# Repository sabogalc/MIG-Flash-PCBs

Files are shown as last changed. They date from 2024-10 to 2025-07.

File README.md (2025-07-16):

# MIG Flash PCBs
This repository hosts KiCad projects of the MIG Dumper and Flashcart PCBs. These files should prove very useful towards understanding the inner workings of the devices, especially with the schematics and boardview files. As-is, not much can be done with the board files since the original boards are programmed at the factory. The only way to currently get a working board from these files is by transplanting at minimum the FPGA and the microcontroller from an OEM MIG device to the new board.

> 
> The 8 pins seen above the USB-C port and to the right of the microcontroller in this photo are the ones used to program the board at the factory (see https://docs.espressif.com/projects/esp-idf/en/v5.2/esp32s2/api-guides/dfu.html for more information)

> 
> The flashcart PCB inside of the game enclosure.

Another useful resource found in this repo is the bill of materials for both devices. If you have a MIG device but a part on it has gone bad or is missing, this repository should assist with finding replacement resistors or capacitors of the correct value, or finding part numbers for components such as the toggle button on the Flashcart. For more information on either board, see their folders in the `KiCad Projects` directory.

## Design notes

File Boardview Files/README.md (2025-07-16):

# Boardview Files

## What is a Boardview File?

A boardview file is a netlist of all the connections on a PCB with every component laid out exactly as it is in real life. This modern approach provides a more intuitive way to inspect connections and troubleshoot PCBs compared to traditional schematic diagrams.

## How Can I View These Files?

Much like how there are many PCB EDA software programs out there, there are also many board viewing programs. The two that I have used and recommend are listed below:

1. **[OpenBoardView](https://github.com/OpenBoardView/OpenBoardView)**  
   - **License:** MIT  
   - **Description:** An open-source tool for viewing boardview files. It provides essential features for inspecting PCB layouts.

2. **[FlexBV](https://pldaniels.com/flexbv/)**  
   - **License:** Commercial (free version available)  
   - **Description:** A commercial tool with advanced features for viewing and analyzing boardview files. The free version offers most of the basic functionalities.

### Example View

Below is a screenshot of the MIG Dumper boardview as viewed in FlexBV:

MIG Dumper Boardview

In this view, you can observe the following:
- **Net Highlighting:** The +3V3 net is highlighted in green across the board.
- **Component Table:** A table on the right lists components and their pin numbers associated with +3V3.
- **Designator Information:** The designators, values of resistors and capacitors, and component footprints are all displayed.

### Note on Metadata

The metadata you see (e.g., component values, designators) is stored in the `.obdata` file. As of July 2025, this metadata is viewable only in FlexBV. The `.obdata` format is [open and documented](https://openboarddata.org/), and I would very much like to see the feature added to OpenBoardView.

### How Can I Create Boardview Files for My Own Designs?

All of the boardview files I make for my projects are using [an open-source KiCad plugin](https://github.com/whitequark/kicad-boardview). When I first came across this plugin, it had a few bugs with current versions of KiCad, so I submitted some pull requests and the plugin is back into perfect operating condition.

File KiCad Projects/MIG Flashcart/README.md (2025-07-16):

# MIG Flashcart

### Overview
The Flashcart board is very compact, and it is a bit challenging to solder it by hand. Most of the passive components are the 0201 size, and the 0404 RGB LED in the top right is also extremely small. Additionally, the vias have been trimmed down to a 0.2mm size to accommodate the board's routing.

A series of leaks in July 2021 made the low-level hardware of the Switch game cartridge reader public, and it is powered by an ASIC called [Lotus3](https://switchbrew.org/wiki/Lotus3). I don't know much about how this chip/protocol works, but the FPGA and microcontroller in this flashcart are programmed to communicate on this custom interface. 

### Ordering Specifications
To ensure this board fits in the game enclosure and that it can be read, it should be ordered as a 0.8mm thick board with an ENIG finish. All other options can be left as their default.

### Component Measurements and BOM Discrepancies
I measured the components to the best of my ability, but there may be slight discrepancies. For example, I found it odd that 12 of the capacitors measured as 0.82uF and 4 of them measured as 0.88uF. I suspect that all of them are 0.82uF, and imperfections in the measurements caused the 4 outliers to read higher values. Even so, they were consistently measuring high enough that I felt it best to mark them as 0.88uF in the schematic. This point is a bit moot, however, because I could not find any 0201 capacitors on either Digikey or Mouser for 0.82uF or 0.88uF. As such, the BOMs have some substitutions, such as 1uF capacitors in place of the 0.82uF and 0.88uF ones, but the measurements in the schematic and PCB are what most align with what I measured in real life.

### Can I use these designs to manufacture my own MIG Flashcart?
The answer is the same as in [the corresponding section of the Dumper's README](https://github.com/sabogalc/MIG-Flash-PCBs/tree/main/KiCad%20Projects/MIG%20Dumper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). Due to the firmware encryption on the original boards, making this board from scratch (e.g. without transplanting the original μC and FPGA) proves to be a bit of a challenge.

Importantly though, the programmer board schematic I made for the Dumper will not work for the Flashcart as-is since the Flashcart has no 5V/VBUS signal. The programmer board would need to be modified to have an onboard 3.3V regulator, and then with this signal on the Flashcart's VCC breakout signal, it should work. Should anyone make that programmer board and want to write their own firmware, the instructions for accomplishing this can be found on [Espressif's website in the bootloader mode note](https://docs.espressif.com/projects/esp-idf/en/v5.2/esp32s2/api-guides/dfu.html).

I have assembled this board with parts from the included BOM and confirmed that it works when using the chips from an OEM MIG Flashcart. If you are using the parts from the BOM, the LED has a pin 1 indicator which I will show in a photo below. Make sure that the white squre between the two gold pins is facing into the board towards the crystal oscillator.

WIN_20250714_21_31_24_Pro

Below are some photos of the board from this repository in the flashcart enclosure.


> 
> The cartridge reading a game in the Switch and showing a green status LED.

### KiCad 3D View
Below are screenshots of the board from KiCad's 3D board viewer.
MIG Flashcart Front
MIG Flashcart Back

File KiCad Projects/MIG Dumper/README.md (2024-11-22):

# MIG Dumper

### Overview
This is a very straightforward board design. The FPGA is is the first point of contact with the cartridge, and it takes care of direct communication with the data and clock lines in order to be able to read the onboard cartridge data. The microcontroller then takes this data from the FPGA, and it relays it to the SD card to USB adapter, presumably through SPI (reference [here](https://switchbrew.org/wiki/Gamecard#Protocol)). With data moving to and from the FPGA/microcontroller in SPI, it is very simple to configure the board as if it were reading an SD card, after which the dumper allows the files to be read by any USB-enabled device.

### Ordering Specifications
The original board is a standard 1.6mm thick board, and all other options (soldermask, surface finish, etc.) can be customized to your liking. Please note that if you are using the OEM enclosure, the 4.7uF capacitor for C29 in the included Digikey/Mouser BOMs is too tall to allow for it to fully close. The capacitor on the original board is 0.85mm tall, but the one I included is 1.6mm tall.

### Component Measurements and BOM Discrepancies
I measured the components to the best of my ability, but there may be slight discrepancies. For example, the aforementioned 4.7uF capacitor was read in real life to be 4.5uF, but I could not find a 1206 4.5uF capacitor on either Digikey or Mouser. As such, the BOMs have some substitutions, such as 100nF capacitors instead of 110nF capacitors, but the measurements in the schematic and PCB are what most align with what I measured in real life. For capacitors in the pF range that I could not measure, I referenced the datasheets for the [ECS-400-10-37B2-CKY-TR](https://ecsxtal.com/store/pdf/ECX-1637B2.pdf) and [MAX20022ATIA+](https://www.analog.com/media/en/technical-documentation/data-sheets/max20021-max20022.pdf) to obtain these values.

Additionally, the SD card to USB adapter chip and the cartridge reader are not present in the BOMs because neither part is available on Digikey or Mouser, but you can purchase both of them from AliExpress.

[GL823K-HCY04 chip](https://www.aliexpress.com/item/3256805047594623.html)

[Cartridge reader](https://www.aliexpress.com/item/3256804487003304.html)

### Can I use these designs to manufacture my own MIG Dumper?
Yes and no. I have succesfully transplanted all the parts of an original Dumper to this PCB, and it works perfectly. Building it from scratch with the parts from the included `.csv` and `.xlsx` BOMs does not work, but if you substitute in an OEM FPGA and ESP32, then it works. This is because the firmware for these chips is programmed and encrypted at the factory, as specified in the main landing page's `README`.

While it may be possible to break this encryption (see [here](https://hackaday.com/2024/01/15/breaking-the-flash-encryption-feature-of-espressifs-microcontrollers/)), I am a hardware engineer and not very interested in delving into the firmware side of things. However, I will include a schematic for a programmer board below should anyone want to embark on that journey. The instructions for the boot sequence needed are found at https://docs.espressif.com/projects/esp-idf/en/v5.2/esp32s2/api-guides/dfu.html in the bootloader mode note.

Programmer Schematic

Below is a photo of the board from this repository screwed into the enclosure and reading a gamecard.
MIG Dumper in enclosure

### KiCad 3D View
Below are screenshots of the board from KiCad's 3D board viewer.
MIG Dumper Front
MIG Dumper Back

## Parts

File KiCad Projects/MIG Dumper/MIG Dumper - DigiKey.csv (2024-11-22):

Index | Quantity | Part Number | Manufacturer Part Number | Description | Customer Reference | Available | Backorder | Unit Price | Extended Price USD
1 | 10 | 1276-1946-1-ND | CL10B105KP8NNNC | CAP CER 1UF 10V X7R 0603 |  | 10 | 0 | 0.01200 | 0.12
2 | 7 | 1276-1000-1-ND | CL10B104KB8NNNC | CAP CER 0.1UF 50V X7R 0603 |  | 7 | 0 | 0.08000 | 0.56
3 | 6 | 1276-1040-1-ND | CL10A225KO8NNNC | CAP CER 2.2UF 16V X5R 0603 |  | 6 | 0 | 0.08000 | 0.48
4 | 4 | 1276-3104-1-ND | CL31B106KOHNFNE | CAP CER 10UF 16V X7R 1206 |  | 4 | 0 | 0.21000 | 0.84
5 | 2 | 399-C0603C100J5GACTUCT-ND | C0603C100J5GACTU | CAP CER 10PF 50V C0G/NP0 0603 |  | 2 | 0 | 0.11000 | 0.22
6 | 2 | 399-17488-1-ND | C1206C825K4PACTU | CAP CER 8.2UF 16V X5R 1206 |  | 2 | 0 | 0.90000 | 1.80
7 | 2 | 1276-2189-1-ND | CL10C150JB81PNC | CAP CER 15PF 50V C0G/NP0 0603 |  | 2 | 0 | 0.10000 | 0.20
8 | 1 | 1276-2208-1-ND | CL10C180JB81PNC | CAP CER 18PF 50V C0G/NP0 0603 |  | 1 | 0 | 0.10000 | 0.10
9 | 1 | 1276-1055-1-ND | CL31B475KAHNNNE | CAP CER 4.7UF 25V X7R 1206 |  | 1 | 0 | 0.17000 | 0.17
10 | 1 | 399-C0603C750K5HACTUCT-ND | C0603C750K5HACTU | CAP CER 75PF 50V X8R 0603 |  | 1 | 0 | 0.10000 | 0.10
11 | 3 | P24.3KHCT-ND | ERJ-3EKF2432V | RES SMD 24.3K OHM 1% 1/10W 0603 |  | 3 | 0 | 0.10000 | 0.30
12 | 2 | P10.0KHCT-ND | ERJ-3EKF1002V | RES SMD 10K OHM 1% 1/10W 0603 |  | 2 | 0 | 0.10000 | 0.20
13 | 2 | P5.10KHCT-ND | ERJ-3EKF5101V | RES SMD 5.1K OHM 1% 1/10W 0603 |  | 2 | 0 | 0.10000 | 0.20
14 | 1 | P56.0KHCT-ND | ERJ-3EKF5602V | RES SMD 56K OHM 1% 1/10W 0603 |  | 1 | 0 | 0.10000 | 0.10
15 | 1 | P19.6KHCT-ND | ERJ-3EKF1962V | RES SMD 19.6K OHM 1% 1/10W 0603 |  | 1 | 0 | 0.10000 | 0.10
16 | 1 | P20.0KHCT-ND | ERJ-3EKF2002V | RES SMD 20K OHM 1% 1/10W 0603 |  | 1 | 0 | 0.10000 | 0.10
17 | 1 | P36.5KHCT-ND | ERJ-3EKF3652V | RES SMD 36.5K OHM 1% 1/10W 0603 |  | 1 | 0 | 0.10000 | 0.10
18 | 1 | P330GCT-ND | ERJ-3GEYJ331V | RES SMD 330 OHM 5% 1/10W 0603 |  | 1 | 0 | 0.10000 | 0.10
19 | 1 | P100KHCT-ND | ERJ-3EKF1003V | RES SMD 100K OHM 1% 1/10W 0603 |  | 1 | 0 | 0.10000 | 0.10
20 | 4 | 490-15985-1-ND | LQM21PN1R5MEHD | FIXED IND 1.5UH 1.5A 125MOHM SMD |  | 4 | 0 | 0.33000 | 1.32
21 | 1 | 754-1940-1-ND | APT3216LSECK/J3-PRV | LED RED CLEAR 2SMD |  | 1 | 0 | 0.64000 | 0.64
22 | 1 | 1965-ESP32-S2FH4CT-ND | ESP32-S2FH4 | RF TXRX MODULE WIFI SMD |  | 1 | 0 | 1.48000 | 1.48
23 | 1 | 220-2212-1-ND | ICE40UP5K-SG48I | IC FPGA 39 I/O 48QFN |  | 1 | 0 | 10.10000 | 10.10
24 | 1 | MAX20022ATIA+-ND | MAX20022ATIA+ | IC REG BUCK ADJ 1A QUAD 28TQFN |  | 1 | 0 | 6.59000 | 6.59
25 | 1 | 50-ECS-400-10-37B2-CKY-TRCT-ND | ECS-400-10-37B2-CKY-TR | CRYSTAL 40.0000MHZ 10PF SMD |  | 1 | 0 | 0.38000 | 0.38
26 | 1 | 2073-USB4105-GF-ACT-ND | USB4105-GF-A | CONN RCP USB2.0 TYP C 24P SMD RA |  | 1 | 0 | 1.04000 | 1.04

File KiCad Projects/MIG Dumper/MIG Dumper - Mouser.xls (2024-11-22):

SHOPPING CART
This is not an invoice
22-Nov-24 03:35:11
 | Mouser # | Mfr. # | Manufacturer | Customer # | Description | RoHS | Lifecycle | Order Qty. | Price (USD) | Ext.: (USD)
1 | 187-CL10B105KP8NNNC | CL10B105KP8NNNC | Samsung Electro-Mechanics |  | Multilayer Ceramic Capacitors MLCC - SMD/SMT 1uF+/-10% 10V X7R 16 0603 | RoHS Compliant |  | 10 | $0.018 | $0.18
2 | 187-CL10B104KB8NNNC | CL10B104KB8NNNC | Samsung Electro-Mechanics |  | Multilayer Ceramic Capacitors MLCC - SMD/SMT 100nF+/-10% 50V X7R 0603 | RoHS Compliant |  | 7 | $0.10 | $0.70
3 | 187-CL10A225KO8NNNC | CL10A225KO8NNNC | Samsung Electro-Mechanics |  | Multilayer Ceramic Capacitors MLCC - SMD/SMT 2.2uF+/-10% 16V X5R 0603 | RoHS Compliant |  | 6 | $0.10 | $0.60
4 | 187-CL31B106KOHNFNE | CL31B106KOHNFNE | Samsung Electro-Mechanics |  | Multilayer Ceramic Capacitors MLCC - SMD/SMT 10uF+/-10% 16V X7R 3 1206 | RoHS Compliant |  | 4 | $0.19 | $0.76
5 | 80-C0603C100J5G | C0603C100J5GACTU | KEMET |  | Multilayer Ceramic Capacitors MLCC - SMD/SMT 50V 10pF C0G 0603 5% | RoHS Compliant |  | 2 | $0.11 | $0.22
6 | 80-C1206C825K4P | C1206C825K4PACTU | KEMET |  | Multilayer Ceramic Capacitors MLCC - SMD/SMT 16V 8.2uF X5R 1206 10% | RoHS Compliant |  | 2 | $0.90 | $1.80
7 | 187-CL10C150JB81PNC | CL10C150JB81PNC | Samsung Electro-Mechanics |  | Multilayer Ceramic Capacitors MLCC - SMD/SMT 15pF+/-5% 50V C0G 16 0603 | RoHS Compliant |  | 2 | $0.10 | $0.20
8 | 187-CL10C180JB81PNC | CL10C180JB81PNC | Samsung Electro-Mechanics |  | Multilayer Ceramic Capacitors MLCC - SMD/SMT 18pF+/-5% 50V C0G 16 0603 | RoHS Compliant |  | 1 | $0.10 | $0.10
9 | 187-CL31B475KAHNNNE | CL31B475KAHNNNE | Samsung Electro-Mechanics |  | Multilayer Ceramic Capacitors MLCC - SMD/SMT 4.7uF+/-10% 25V X7R 3216 | RoHS Compliant |  | 1 | $0.17 | $0.17
10 | 80-C0603C750K5HACTU | C0603C750K5HACTU | KEMET |  | Multilayer Ceramic Capacitors MLCC - SMD/SMT 50V 75pF X8R 0603 10% | RoHS Compliant |  | 1 | $0.10 | $0.10
11 | 667-ERJ-3EKF2432V | ERJ-3EKF2432V | Panasonic |  | Thick Film Resistors - SMD 0603 24.3Kohms 1% AEC-Q200 | RoHS Compliant By Exemption |  | 3 | $0.10 | $0.30
12 | 667-ERJ-3EKF1002V | ERJ-3EKF1002V | Panasonic |  | Thick Film Resistors - SMD 0603 10Kohms 1% AEC-Q200 | RoHS Compliant By Exemption |  | 2 | $0.10 | $0.20
13 | 667-ERJ-3EKF5101V | ERJ-3EKF5101V | Panasonic |  | Thick Film Resistors - SMD 0603 5.1Kohms 1% AEC-Q200 | RoHS Compliant By Exemption |  | 2 | $0.10 | $0.20
14 | 667-ERJ-3EKF5602V | ERJ-3EKF5602V | Panasonic |  | Thick Film Resistors - SMD 0603 56Kohms 1% AEC-Q200 | RoHS Compliant By Exemption |  | 1 | $0.10 | $0.10
15 | 667-ERJ-3EKF1962V | ERJ-3EKF1962V | Panasonic |  | Thick Film Resistors - SMD 0603 19.6Kohms 1% AEC-Q200 | RoHS Compliant By Exemption |  | 1 | $0.10 | $0.10
16 | 667-ERJ-3EKF2002V | ERJ-3EKF2002V | Panasonic |  | Thick Film Resistors - SMD 0603 20Kohms 1% AEC-Q200 | RoHS Compliant By Exemption |  | 1 | $0.10 | $0.10
17 | 667-ERJ-3EKF3652V | ERJ-3EKF3652V | Panasonic |  | Thick Film Resistors - SMD 0603 36.5Kohms 1% AEC-Q200 | RoHS Compliant By Exemption |  | 1 | $0.10 | $0.10
18 | 667-ERJ-3GEYJ331V | ERJ-3GEYJ331V | Panasonic |  | Thick Film Resistors - SMD 0603 330ohms 5% AEC-Q200 | RoHS Compliant By Exemption |  | 1 | $0.10 | $0.10
19 | 667-ERJ-3EKF1003V | ERJ-3EKF1003V | Panasonic |  | Thick Film Resistors - SMD 0603 100Kohms 1% AEC-Q200 | RoHS Compliant By Exemption |  | 1 | $0.10 | $0.10
20 | 81-LQM21PN1R5MEHD | LQM21PN1R5MEHD | Murata |  | Power Inductors - SMD 1.5 UH +-20% 1.5A RDC=0.125 | RoHS Compliant |  | 4 | $0.33 | $1.32
21 | 604-APT3216LSECKJ3RV | APT3216LSECK/J3-PRV | Kingbright |  | Standard LEDs - SMD 3.2X1.6MM LOW CRNT | RoHS Compliant |  | 1 | $0.59 | $0.59
22 | 356-ESP32-S2FH4 | ESP32-S2FH4 | Espressif |  | RF System on a Chip - SoC SMD Wi-Fi IC, ESP32-S2FH4, single-core MCU, 4 MB flash die inside, QFN 56-pin, 7*7 mm, -40 C - +105 C | RoHS Compliant |  | 1 | $1.48 | $1.48
23 | 842-ICE40UP5K-SG48I | ICE40UP5K-SG48I | Lattice |  | FPGA - Field Programmable Gate Array iCE40 UltraPlus, 5280 LUTs, 1.2V | RoHS Compliant |  | 1 | $10.10 | $10.10
24 | 700-MAX20022ATIA+ | MAX20022ATIA+ | Analog Devices Inc. |  | Switching Voltage Regulators Quad, Low-Voltage Step-Down DC-DC Conver | RoHS Compliant |  | 1 | $6.59 | $6.59
25 | 520-400-10-37B2CKYTR | ECS-400-10-37B2-CKY-TR | ECS |  | Crystals 40.000 MHz 10 pF +/-10 +/-10 -30 +85 C +/-2 ppm Max. ESR = 40 | RoHS Compliant |  | 1 | $0.38 | $0.38
26 | 640-USB4105-GF-A | USB4105-GF-A | Global Connector Technology (GCT) |  | USB Connectors USB Type C,2.0, Rec,SMT, 0.95mmTH Shell Stakes,G/F,RA,Top Mnt,T&R | RoHS Compliant |  | 1 | $0.92 | $0.92
By submitting your order you agree to these terms and conditions. (https://www.mouser.com/saleterms) |  |  |  |  |  |  |  |  | Merchandise: | $27.51
Prices are reflected at the date and time shown. |  |  |  |  |  |  |  |  | Shipping Charge: | $7.99

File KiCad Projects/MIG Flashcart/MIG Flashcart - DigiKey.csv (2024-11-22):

Index | Quantity | Part Number | Manufacturer Part Number | Description | Customer Reference | Available | Backorder | Unit Price | Extended Price USD
1 | 16 | 490-7229-1-ND | GRM033R60J105MEA2D | CAP CER 1UF 6.3V X5R 0201 |  | 16 | 0 | 0.01400 | 0.22
2 | 2 | 490-8607-1-ND | GRM0335C1E100JA01D | CAP CER 10PF 25V C0G/NP0 0201 |  | 2 | 0 | 0.10000 | 0.20
3 | 1 | 399-C0402C335M7PACTUCT-ND | C0402C335M7PACTU | CAP CER 3.3UF 4V X5R 0402 |  | 1 | 0 | 0.50000 | 0.50
4 | 3 | P122936CT-ND | ERJ-1GNF3300C | RES SMD 330 OHM 1% 1/20W 0201 |  | 3 | 0 | 0.10000 | 0.30
5 | 1 | P123338CT-ND | ERJ-1GNJ510C | RES SMD 51 OHM 5% 1/20W 0201 |  | 1 | 0 | 0.10000 | 0.10
6 | 1 | P122414CT-ND | ERJ-1GNF1002C | RES SMD 10K OHM 1% 1/20W 0201 |  | 1 | 0 | 0.10000 | 0.10
7 | 1 | P122413CT-ND | ERJ-1GNF1001C | RES SMD 1K OHM 1% 1/20W 0201 |  | 1 | 0 | 0.10000 | 0.10
8 | 1 | 90-UHD111A-FKA-C3K23E1L3VG5ZB3Z3-ND | UHD111A-FKA-C3K23E1L3VG5ZB3Z3 | LED RGB 0404 SMD |  | 1 | 0 | 0.10000 | 0.10
9 | 1 | 220-2212-1-ND | ICE40UP5K-SG48I | IC FPGA 39 I/O 48QFN |  | 1 | 0 | 10.10000 | 10.10
10 | 1 | 1965-ESP32-S2FH4CT-ND | ESP32-S2FH4 | RF TXRX MODULE WIFI SMD |  | 1 | 0 | 1.48000 | 1.48
11 | 1 | 296-27438-1-ND | TLV70012DCKR | IC REG LINEAR 1.2V 200MA SC70-5 |  | 1 | 0 | 0.22000 | 0.22
12 | 1 | 296-27793-1-ND | TLV70025DCKR | IC REG LINEAR 2.5V 200MA SC70-5 |  | 1 | 0 | 0.21000 | 0.21
13 | 1 | 50-ECS-400-10-37B2-CKY-TRCT-ND | ECS-400-10-37B2-CKY-TR | CRYSTAL 40.0000MHZ 10PF SMD |  | 1 | 0 | 0.38000 | 0.38
14 | 1 | P16763CT-ND | EVQ-P7A01P | SWITCH TACTILE SPST-NO 0.05A 12V |  | 1 | 0 | 0.33000 | 0.33
15 | 1 | WM6357CT-ND | 1040310811 | CONN MICRO SD CARD PUSH-PULL R/A |  | 1 | 0 | 2.30000 | 2.30

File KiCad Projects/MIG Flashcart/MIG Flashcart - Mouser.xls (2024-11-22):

SHOPPING CART
This is not an invoice
22-Nov-24 04:05:19
 | Mouser # | Mfr. # | Manufacturer | Customer # | Description | RoHS | Lifecycle | Order Qty. | Price (USD) | Ext.: (USD)
1 | 81-GRM033R60J105ME2D | GRM033R60J105MEA2D | Murata |  | Multilayer Ceramic Capacitors MLCC - SMD/SMT 1 uF 6.3 VDC 20% 0201 X5R | RoHS Compliant |  | 16 | $0.018 | $0.29
2 | 81-GRM0335C1E100JA1D | GRM0335C1E100JA01D | Murata |  | Multilayer Ceramic Capacitors MLCC - SMD/SMT 10 pF 25 VDC 5% 0201 C0G (NP0) | RoHS Compliant |  | 2 | $0.10 | $0.20
3 | 80-C0402C335M7P | C0402C335M7PACTU | KEMET |  | Multilayer Ceramic Capacitors MLCC - SMD/SMT 4V 3.3uF X5R 0402 20% | RoHS Compliant |  | 1 | $0.50 | $0.50
4 | 667-ERJ-1GNF3300C | ERJ-1GNF3300C | Panasonic |  | Thick Film Resistors - SMD 0201 330ohm 1% HalogenFree AEC-Q200 | RoHS Compliant By Exemption |  | 3 | $0.10 | $0.30
5 | 667-ERJ-1GNJ510C | ERJ-1GNJ510C | Panasonic |  | Thick Film Resistors - SMD 0201 51ohms 5% Thick Film Resistor | RoHS Compliant By Exemption |  | 1 | $0.10 | $0.10
6 | 667-ERJ-1GNF1002C | ERJ-1GNF1002C | Panasonic |  | Thick Film Resistors - SMD 0201 10Kohm 1% HalogenFree AEC-Q200 | RoHS Compliant By Exemption |  | 1 | $0.10 | $0.10
7 | 667-ERJ-1GNF1001C | ERJ-1GNF1001C | Panasonic |  | Thick Film Resistors - SMD 0201 1Kohm 1% HalogenFree AEC-Q200 | RoHS Compliant By Exemption |  | 1 | $0.10 | $0.10
8 | 941-UHD1AA3K3E3V53Z3 | UHD111A-FKA-C3K23E1L3VG5ZB3Z3 | Cree LED |  | Standard LEDs - SMD RGB LED SMD | RoHS Compliant |  | 1 | $0.10 | $0.10
9 | 842-ICE40UP5K-SG48I | ICE40UP5K-SG48I | Lattice |  | FPGA - Field Programmable Gate Array iCE40 UltraPlus, 5280 LUTs, 1.2V | RoHS Compliant |  | 1 | $10.10 | $10.10
10 | 356-ESP32-S2FH4 | ESP32-S2FH4 | Espressif |  | RF System on a Chip - SoC SMD Wi-Fi IC, ESP32-S2FH4, single-core MCU, 4 MB flash die inside, QFN 56-pin, 7*7 mm, -40 C - +105 C | RoHS Compliant |  | 1 | $1.48 | $1.48
11 | 595-TLV70012DCKR | TLV70012DCKR | Texas Instruments |  | LDO Voltage Regulators 200mA,Lo IQ,LDO Reg | RoHS Compliant |  | 1 | $0.22 | $0.22
12 | 595-TLV70025DCKR | TLV70025DCKR | Texas Instruments |  | LDO Voltage Regulators 200mALo IQLDO Reg | RoHS Compliant |  | 1 | $0.21 | $0.21
13 | 520-400-10-37B2CKYTR | ECS-400-10-37B2-CKY-TR | ECS |  | Crystals 40.000 MHz 10 pF +/-10 +/-10 -30 +85 C +/-2 ppm Max. ESR = 40 | RoHS Compliant |  | 1 | $0.38 | $0.38
14 | 667-EVQP7A01P | EVQ-P7A01P | Panasonic |  | Tactile Switches 3.5x2.9mm Right Ang Light Touch Switch | RoHS Compliant |  | 1 | $0.29 | $0.29
15 | 538-104031-0811 | 104031-0811 | Molex |  | Memory Card Connectors MICRO SD PUSH-PULL SMT 1.42MM HEIGHT | RoHS Compliant |  | 1 | $2.30 | $2.30
By submitting your order you agree to these terms and conditions. (https://www.mouser.com/saleterms) |  |  |  |  |  |  |  |  | Merchandise: | $16.67
Prices are reflected at the date and time shown. |  |  |  |  |  |  |  |  | Shipping Charge: | $7.99

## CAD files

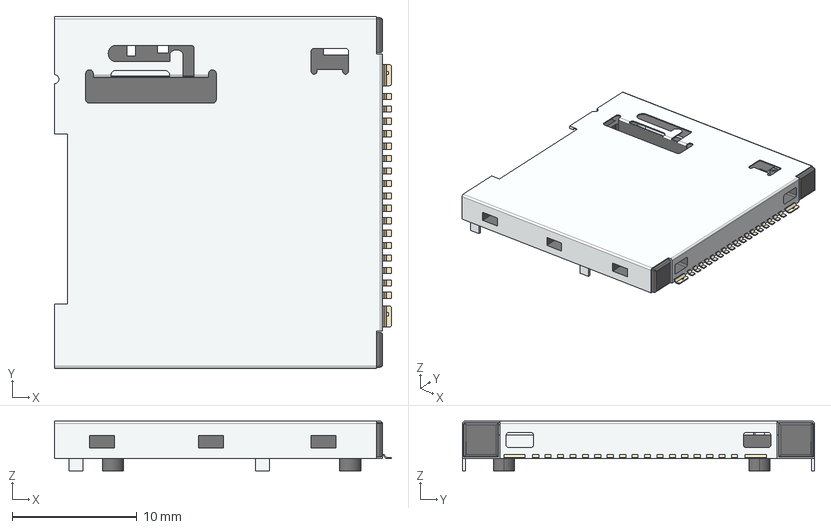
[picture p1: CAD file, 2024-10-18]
KiCad Projects/MIG Dumper/STEP Files/Switch Cartridge.step
27.1 x 28.2 x 4.00 mm
model with colors
model with colors001
model with colors002
model with colors003
model with colors004
model with colors005
model with colors006
model with colors007
model with colors008
model with colors009
model with colors010
model with colors011
model with colors012
model with colors013
model with colors014
model with colors015
model with colors016
model with colors017
model with colors018
model with colors019
model with colors020
model with colors021
model with colors022
model with colors023
model with colors024
model with colors025
model with colors026
model with colors027
model with colors028
model with colors029
model with colors030
model with colors031
model with colors032
model with colors033
model with colors034
model with colors035
model with colors036
model with colors037
model with colors038
model with colors039
model with colors040
model with colors041
model with colors042
model with colors043
model with colors044
model with colors045
model with colors046
model with colors047
model with colors048
model with colors049
model with colors050
model with colors051
model with colors052
model with colors053
model with colors054
model with colors055
model with colors056
model with colors057
model with colors058
model with colors059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

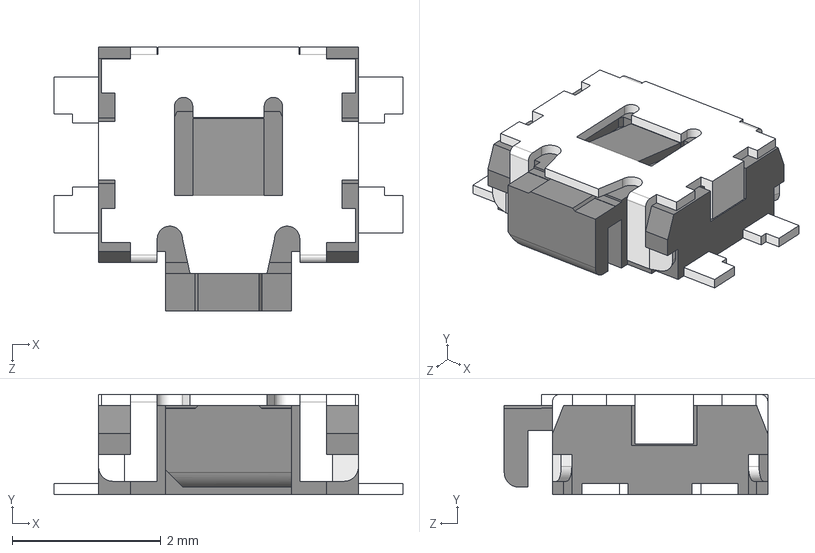
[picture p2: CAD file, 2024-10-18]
KiCad Projects/MIG Flashcart/STEP Files/EVQ-P7A01P.stp
4.70 x 1.35 x 3.55 mm

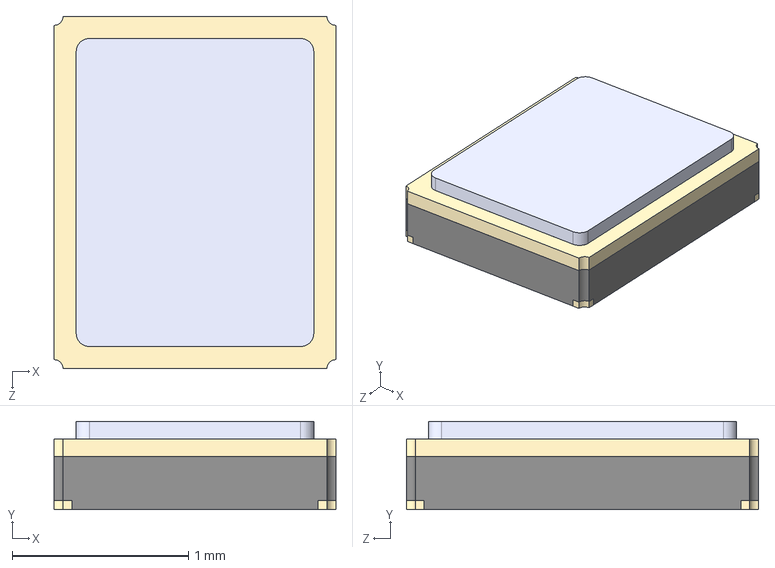
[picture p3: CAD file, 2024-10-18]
KiCad Projects/MIG Dumper/STEP Files/ECS-400-10-37B2-CKY-TR.step
1.60 x 0.5 x 2.00 mm

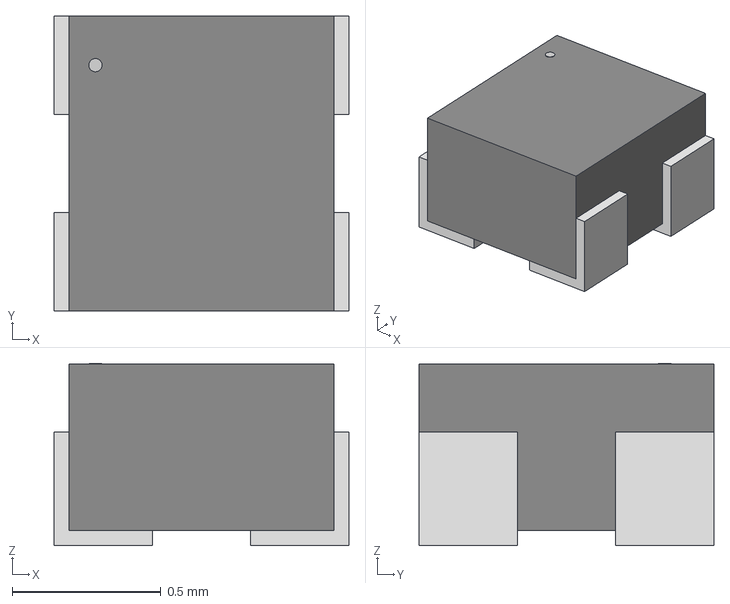
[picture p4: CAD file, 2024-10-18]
KiCad Projects/MIG Flashcart/STEP Files/SMD4_UHD111A-FKA_CRW.step
0.99 x 0.99 x 0.612 mm

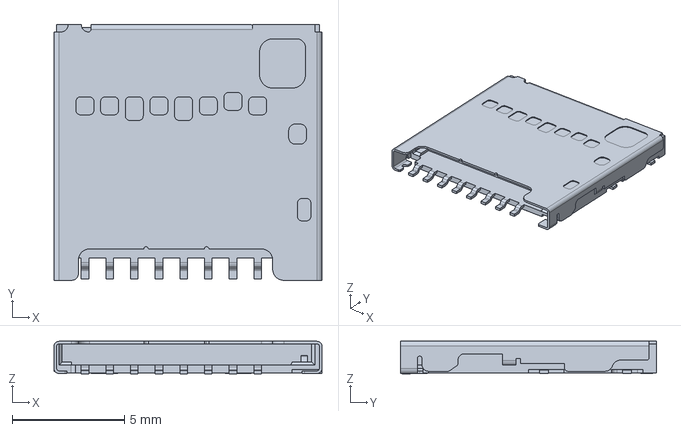
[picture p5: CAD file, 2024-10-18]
KiCad Projects/MIG Flashcart/STEP Files/104031-0811.step
11.9 x 11.4 x 1.45 mm

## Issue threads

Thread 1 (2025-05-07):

Does the FPGA have internal ROM?

MainSilent, 2025-05-07:
Hey
Can you confirm if the FPGA chip has `NVCM`?

sabogalc, 2025-05-07:
I'm not sure how to check for this, can you let me know how to do so? The only pins I see broken out for programming are for the ESP32 so I would need some guidance on where and how to tap into the FPGA to check for what you're asking about.

MainSilent, 2025-05-07:
That would be great news if it's the case. Is there anything written on the FPGA IC besides `ICE40UP5K-SG48ITR`?
Even though ESP32 is connected to pins such as `CDONE` and `CRESET` but sdcard is not connected to ESP32 and I'm not sure if it has stored the initial firmware internally since it has very little memory for the bootloader.

MainSilent, 2025-05-07:
Never mind.
According to the datasheet it does have NVCM
Deadlock Again :(

MainSilent, 2025-05-13:
New Discovery
It's the FPGA that loads the Program to the esp32 and not vice versa.
It appears they have burned efuse to change SPI Flash connections (Probably for better trace routing)
The FPGA Act as SPI Flash for the ESP32

MainSilent, 2025-05-13:
But I'm still confused on why they would use a micro-controller for logic controls since that can also be done on FPGA

MainSilent, 2025-05-13:
Can you check to see if by removing the esp32, Flashcard would still work?

Closed 2025-05-07.

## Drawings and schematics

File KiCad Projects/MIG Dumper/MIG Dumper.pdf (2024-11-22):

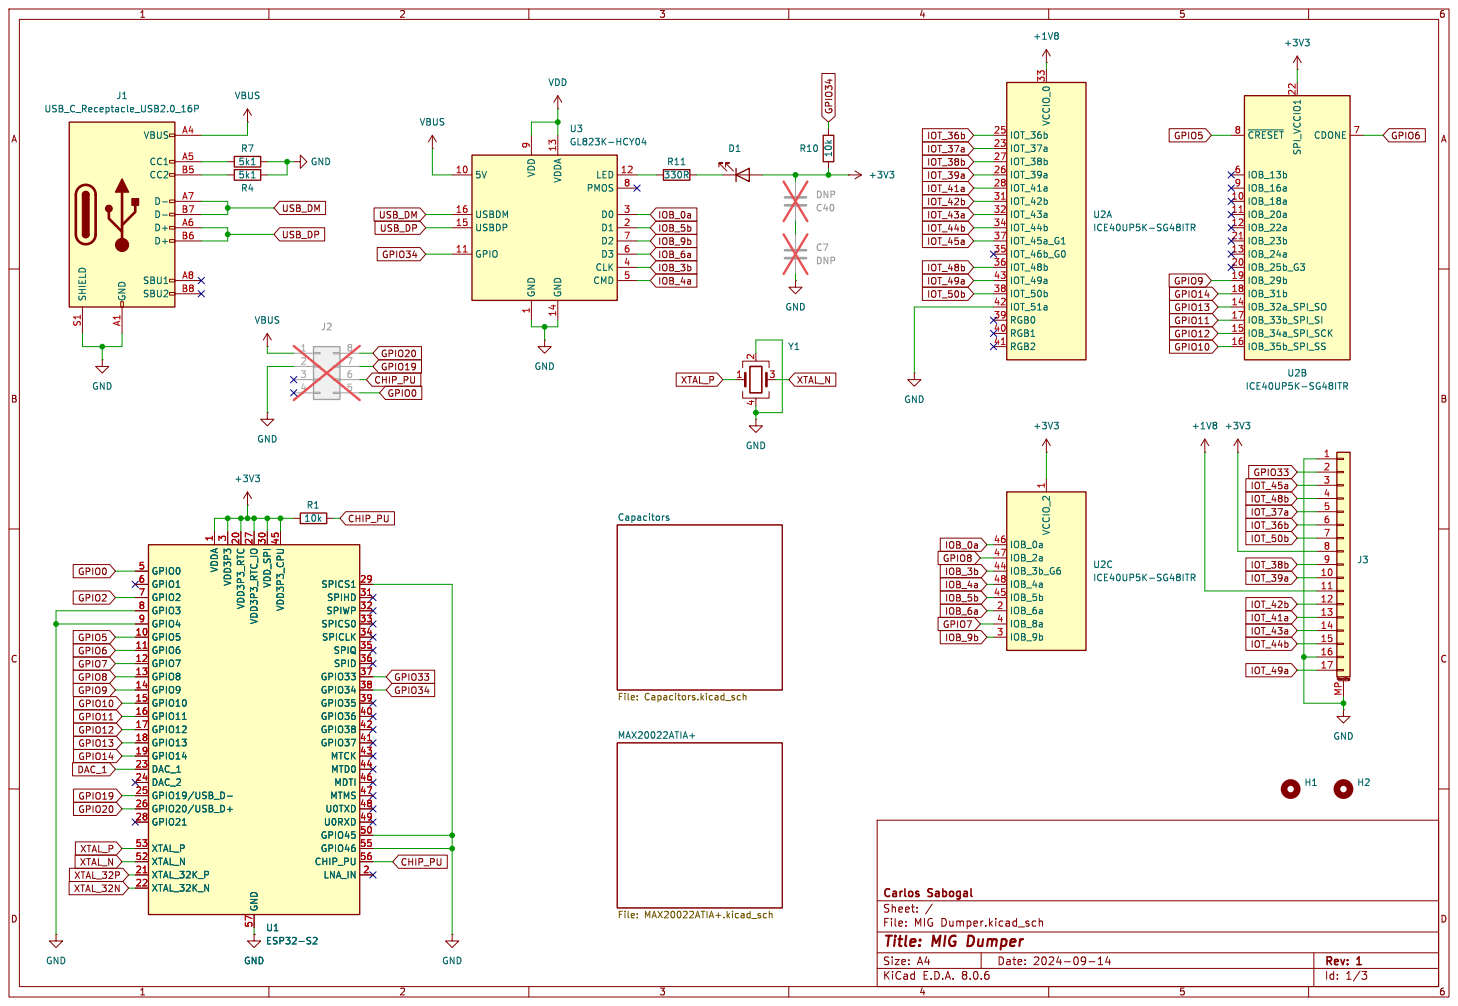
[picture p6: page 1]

3 VDD_SPI 30 SPIHD 31 SPIWP 32 SPICS0 33 SPICLK 34 SPIQ 35 SPID 36 GPIO33 37 GPIO34 38 GPIO35 39 GPIO36 40 GPIO37 41 GPIO38 42 MTCK 43 MTD0 44 VDD3P3_CPU 45 MDTI 46 MTMS 47 U0TXD 48 U0RXD 49 GPIO0 5 GPIO45 50 XTAL_N 52 XTAL_P 53 GPIO46 55 CHIP_PU 56 GND 57 GPIO1 6 GPIO2 7 GPIO3 8 GPIO4 9 U1ESP32-S2

3 VDD_SPI 30 SPIHD 31 SPIWP 32 SPICS0 33 SPICLK 34 SPIQ 35 SPID 36 GPIO33 37 GPIO34 38 GPIO35 39 GPIO36 40 GPIO37 41 GPIO38 42 MTCK 43 MTD0 44 VDD3P3_CPU 45 MDTI 46 MTMS 47 U0TXD 48 U0RXD 49 GPIO0 5 GPIO45 50 XTAL_N 52 XTAL_P 53 GPIO46 55 CHIP_PU 56 GND 57 GPIO1 6 GPIO2 7 GPIO3 8 GPIO4 9 GND

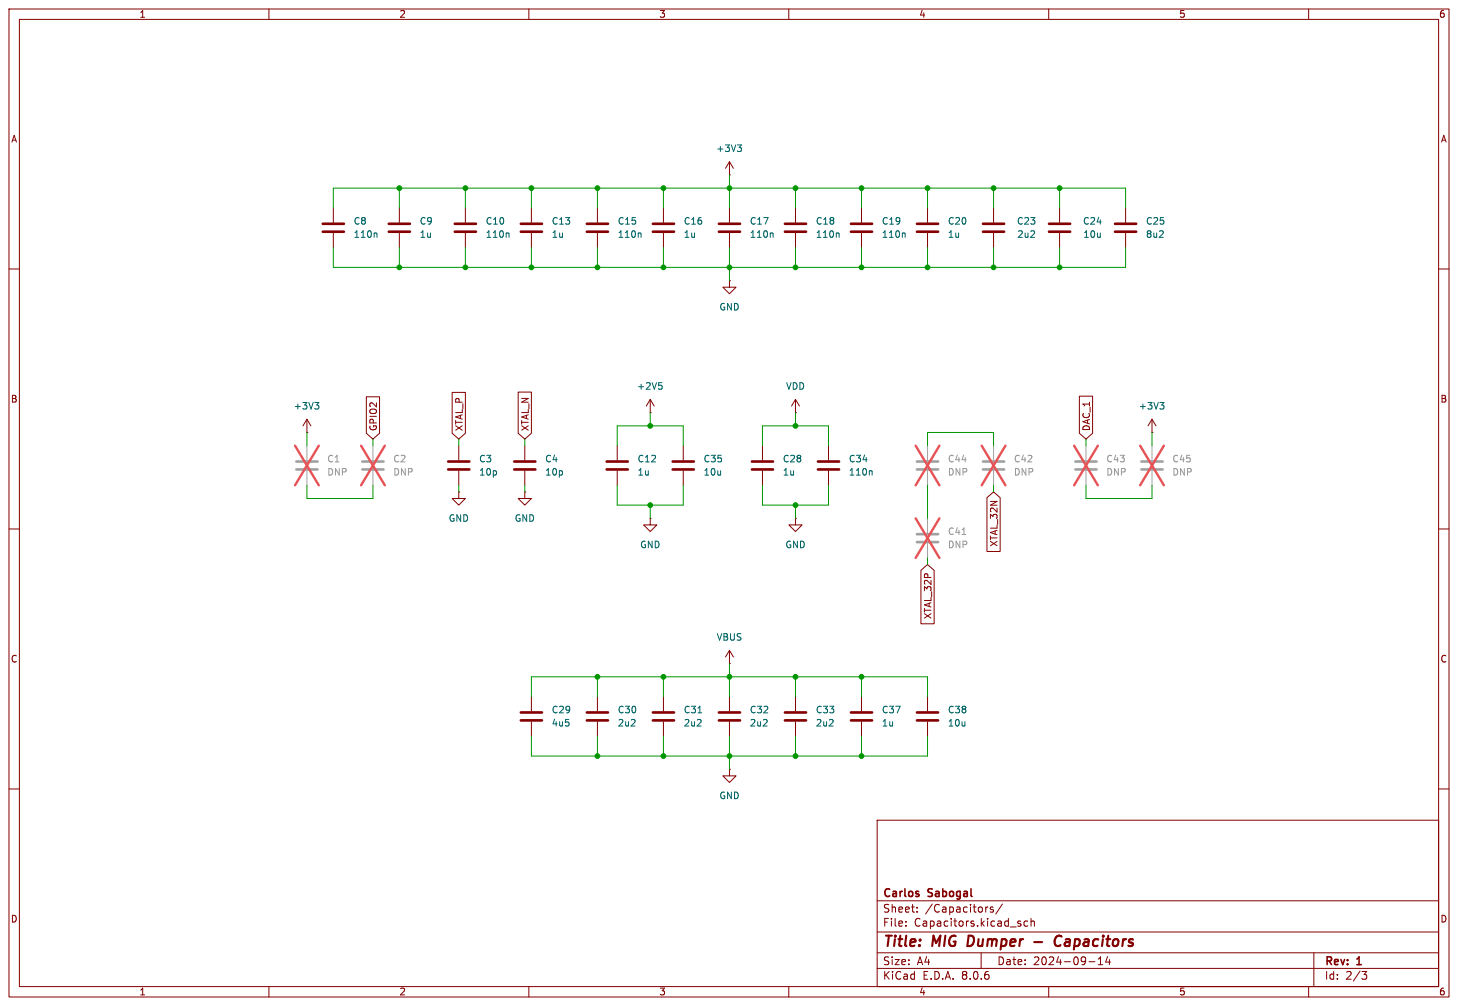
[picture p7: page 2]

File: Capacitors.kicad_sch Sheet: /Capacitors/ Carlos Sabogal GND

Id: 2/3 Title: MIG Dumper - Capacitors

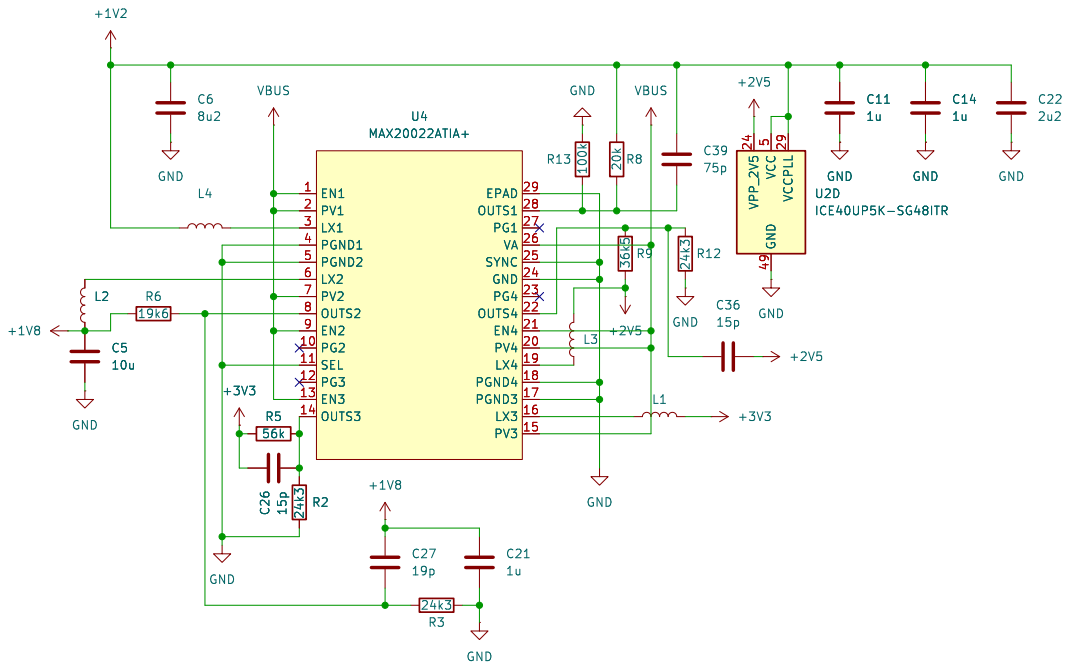
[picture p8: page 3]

File: MAX20022ATIA+.kicad_sch Sheet: /MAX20022ATIA+/ Carlos Sabogal

Id: 3/3 Title: MIG Dumper - MAX20022ATIA+

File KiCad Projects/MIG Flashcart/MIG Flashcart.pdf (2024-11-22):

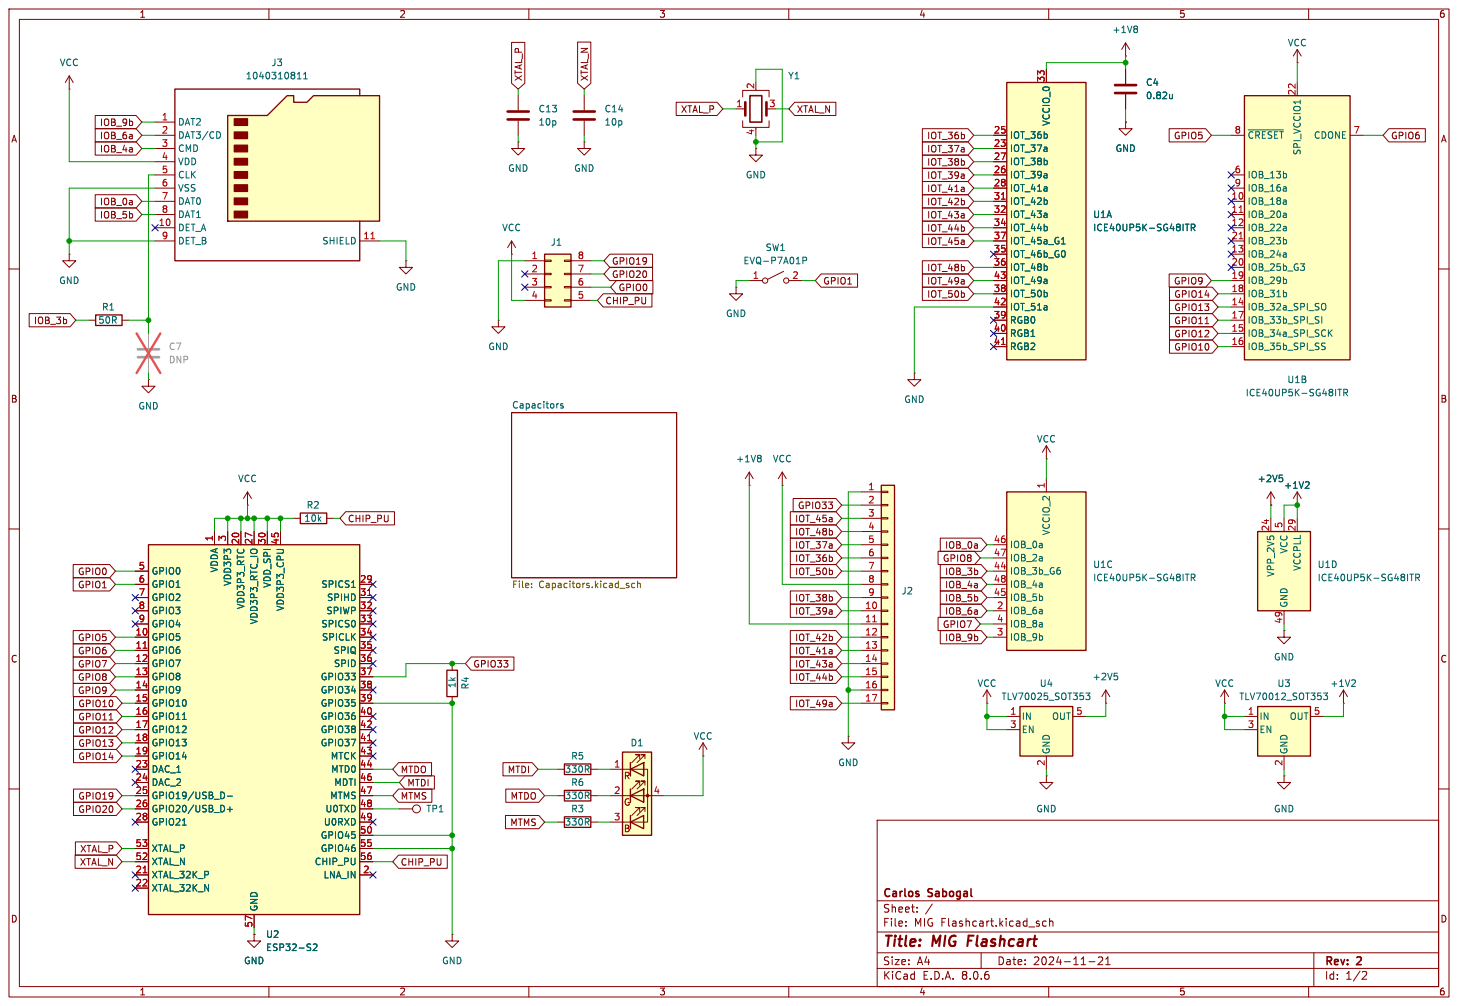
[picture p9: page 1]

Capacitors File: Capacitors.kicad_sch GND

3 VDD_SPI 30 SPIHD 31 SPIWP 32 SPICS0 33 SPICLK 34 SPIQ 35 SPID 36 GPIO33 37 GPIO34 38 GPIO35 39 GPIO36 40 GPIO37 41 GPIO38 42 MTCK 43 MTD0 44 VDD3P3_CPU 45 MDTI 46 MTMS 47 U0TXD 48 U0RXD 49 GPIO0 5 GPIO45 50 XTAL_N 52 XTAL_P 53 GPIO46 55 CHIP_PU 56 GND 57 GPIO1 6 GPIO2 7 GPIO3 8 GPIO4 9 U2ESP32-S2 GND

3 VDD_SPI 30 SPIHD 31 SPIWP 32 SPICS0 33 SPICLK 34 SPIQ 35 SPID 36 GPIO33 37 GPIO34 38 GPIO35 39 GPIO36 40 GPIO37 41 GPIO38 42 MTCK 43 MTD0 44 VDD3P3_CPU 45 MDTI 46 MTMS 47 U0TXD 48 U0RXD 49 GPIO0 5 GPIO45 50 XTAL_N 52 XTAL_P 53 GPIO46 55 CHIP_PU 56 GND 57 GPIO1 6 GPIO2 7 GPIO3 8 GPIO4 9 GND

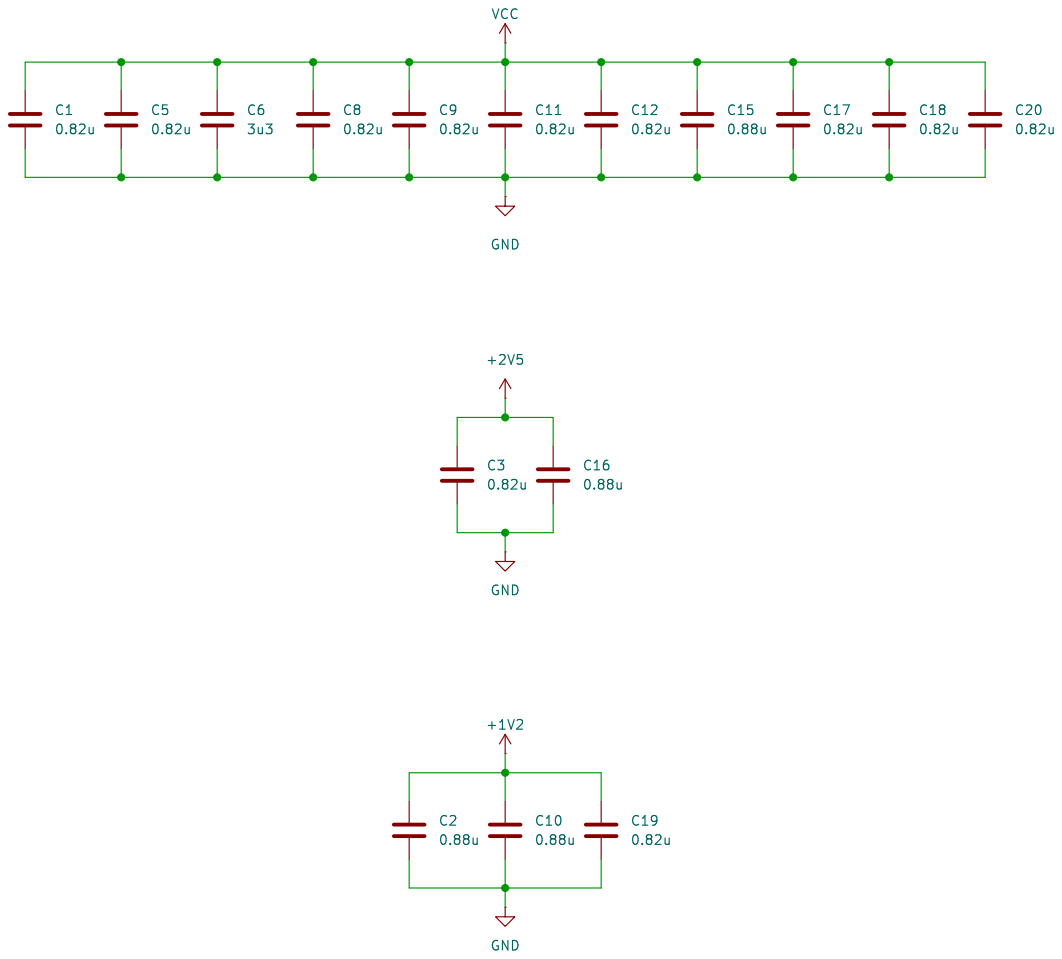
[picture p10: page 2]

File: Capacitors.kicad_sch Sheet: /Capacitors/ Carlos Sabogal

Id: 2/2 Title: MIG Flashcart - Capacitors

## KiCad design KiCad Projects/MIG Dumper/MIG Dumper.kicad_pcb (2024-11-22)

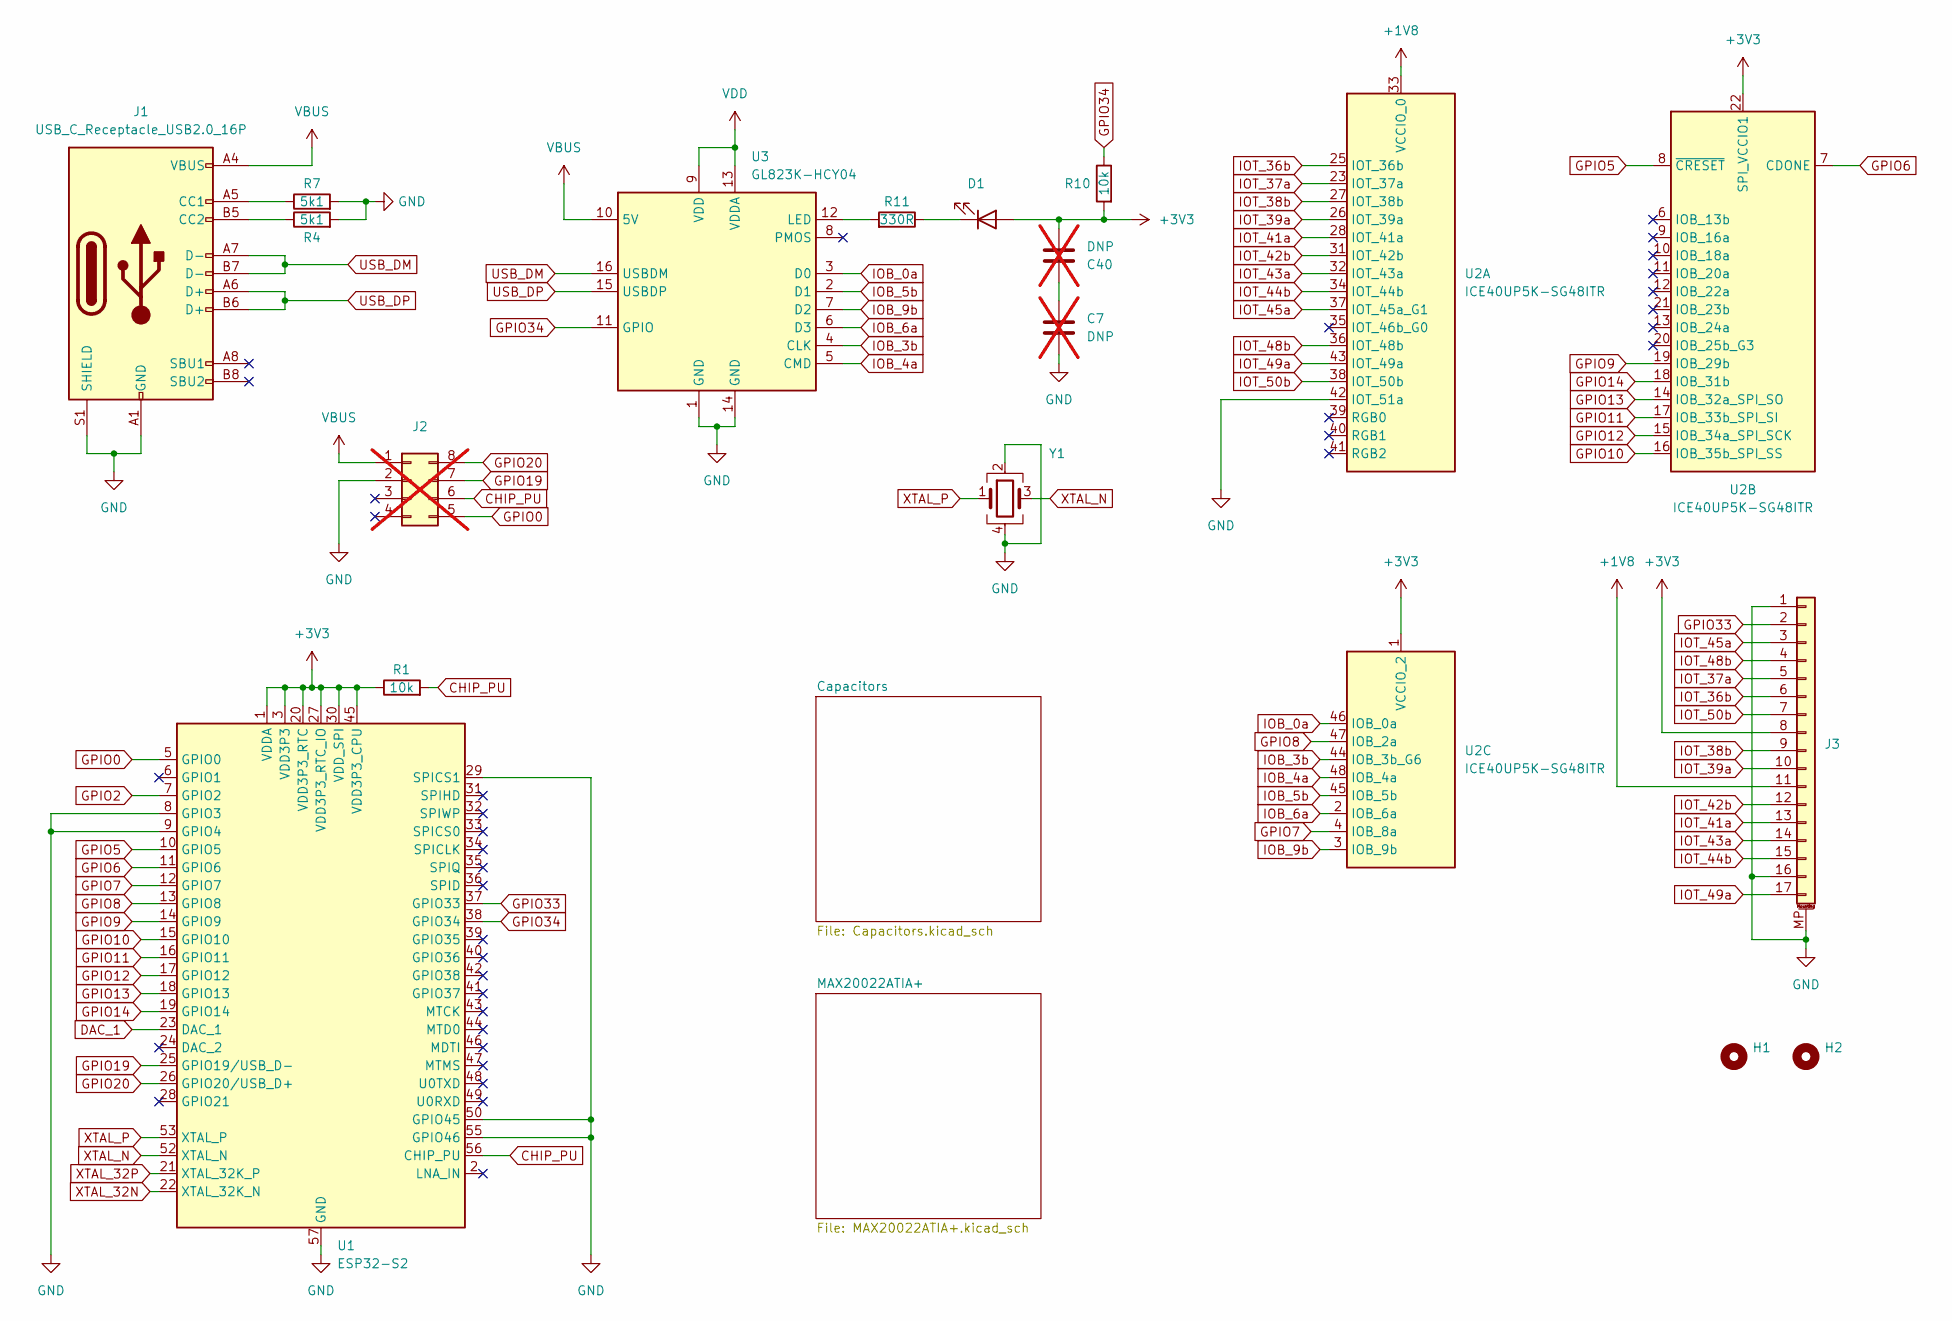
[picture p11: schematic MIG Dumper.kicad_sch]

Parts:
C7: DNP; C_1206_3216Metric_Pad1.33x1.80mm_HandSolder; not fitted
C40: DNP; C_0603_1608Metric; not fitted
D1: APT3216LSECK/J3-PRV; LED_1206_3216Metric_Pad1.42x1.75mm_HandSolder
H1, H2: MountingHole; MountingHole_2.2mm_M2_DIN965_Pad_TopBottom
J1: USB_C_Receptacle_USB2.0_16P; USB_C_Receptacle_GCT_USB4105-xx-A_16P_TopMnt_Horizontal
J2: Conn_02x04_Counter_Clockwise; PinHeader_2x04_P1.27mm_Vertical; not fitted
J3: Conn_01x17_MountingPin; Switch_Cartridge
R1, R10: 10k; R_0603_1608Metric
R4, R7: 5k1; R_0603_1608Metric
R11: 330R; R_0603_1608Metric
U1: ESP32-S2; QFN-56-1EP_7x7mm_P0.4mm_EP4x4mm
U2: ICE40UP5K-SG48ITR; QFN-48-1EP_7x7mm_P0.5mm_EP5.15x5.15mm
U3: GL823K-HCY04; SSOP-16_3.9x4.9mm_P0.635mm
Y1: ECS-400-10-37B2-CKY-TR; Crystal_SMD_SeikoEpson_FA128-4Pin_2.0x1.6mm

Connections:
+1V8: J3.11, U2.33 (VCCIO_0); also elsewhere on the board
+3V3: C40.2, D1.2 (A), J3.8, R1.1, R10.2, U1.1 (VDDA), U1.3 (VDD3P3), U1.4 (VDD3P3), U1.20 (VDD3P3_RTC), U1.27 (VDD3P3_RTC_IO), U1.30 (VDD_SPI), U1.45 (VDD3P3_CPU), U1.51 (VDDA), U1.54 (VDDA), U2.1 (VCCIO_2), U2.22 (SPI_VCCIO1); also elsewhere on the board
CHIP_PU: J2.6, R1.2, U1.56 (CHIP_PU)
DAC_1: U1.23 (DAC_1); also elsewhere on the board
GND: C7.2, J1.A1 (GND), J1.A12 (GND), J1.B1 (GND), J1.B12 (GND), J1.S1 (SHIELD), J2.2, J3.1, J3.16, J3.MP (MountPin), R4.2, R7.2, U1.8 (GPIO3), U1.9 (GPIO4), U1.29 (SPICS1), U1.50 (GPIO45), U1.55 (GPIO46), U1.57 (GND), U2.42 (IOT_51a), U3.1 (GND), U3.14 (GND), Y1.2, Y1.4; also elsewhere on the board
GPIO0: J2.5, U1.5 (GPIO0)
GPIO2: U1.7 (GPIO2); also elsewhere on the board
GPIO5: U1.10 (GPIO5), U2.8 (~CRESET)
GPIO6: U1.11 (GPIO6), U2.7 (CDONE)
GPIO7: U1.12 (GPIO7), U2.4 (IOB_8a)
GPIO8: U1.13 (GPIO8), U2.47 (IOB_2a)
GPIO9: U1.14 (GPIO9), U2.19 (IOB_29b)
GPIO10: U1.15 (GPIO10), U2.16 (IOB_35b_SPI_SS)
GPIO11: U1.16 (GPIO11), U2.17 (IOB_33b_SPI_SI)
GPIO12: U1.17 (GPIO12), U2.15 (IOB_34a_SPI_SCK)
GPIO13: U1.18 (GPIO13), U2.14 (IOB_32a_SPI_SO)
GPIO14: U1.19 (GPIO14), U2.18 (IOB_31b)
GPIO19: J2.7, U1.25 (GPIO19/USB_D-)
GPIO20: J2.8, U1.26 (GPIO20/USB_D+)
GPIO33: J3.2, U1.37 (GPIO33)
GPIO34: R10.1, U1.38 (GPIO34), U3.11 (GPIO)
IOB_0a: U2.46 (IOB_0a), U3.3 (D0)
IOB_3b: U2.44 (IOB_3b_G6), U3.4 (CLK)
IOB_4a: U2.48 (IOB_4a), U3.5 (CMD)
IOB_5b: U2.45 (IOB_5b), U3.2 (D1)
IOB_6a: U2.2 (IOB_6a), U3.6 (D3)
IOB_9b: U2.3 (IOB_9b), U3.7 (D2)
IOT_36b: J3.6, U2.25 (IOT_36b)
IOT_37a: J3.5, U2.23 (IOT_37a)
IOT_38b: J3.9, U2.27 (IOT_38b)
IOT_39a: J3.10, U2.26 (IOT_39a)
IOT_41a: J3.13, U2.28 (IOT_41a)
IOT_42b: J3.12, U2.31 (IOT_42b)
IOT_43a: J3.14, U2.32 (IOT_43a)
IOT_44b: J3.15, U2.34 (IOT_44b)
IOT_45a: J3.3, U2.37 (IOT_45a_G1)
IOT_48b: J3.4, U2.36 (IOT_48b)
IOT_49a: J3.17, U2.43 (IOT_49a)
IOT_50b: J3.7, U2.38 (IOT_50b)
unnamed: C7.1, C40.1
unnamed: D1.1 (K), R11.1
unnamed: J1.A5 (CC1), R7.1
unnamed: J1.B5 (CC2), R4.1
unnamed: R11.2, U3.12 (LED)
USB_DM: J1.A7 (D-), J1.B7 (D-), U3.16 (USBDM)
USB_DP: J1.A6 (D+), J1.B6 (D+), U3.15 (USBDP)
VBUS: J1.A4 (VBUS), J1.A9 (VBUS), J1.B4 (VBUS), J1.B9 (VBUS), J2.1, U3.10 (5V); also elsewhere on the board
VDD: U3.9 (VDD), U3.13 (VDDA); also elsewhere on the board
XTAL_32N: U1.22 (XTAL_32K_N); also elsewhere on the board
XTAL_32P: U1.21 (XTAL_32K_P); also elsewhere on the board
XTAL_N: U1.52 (XTAL_N), Y1.3; also elsewhere on the board
XTAL_P: U1.53 (XTAL_P), Y1.1; also elsewhere on the board

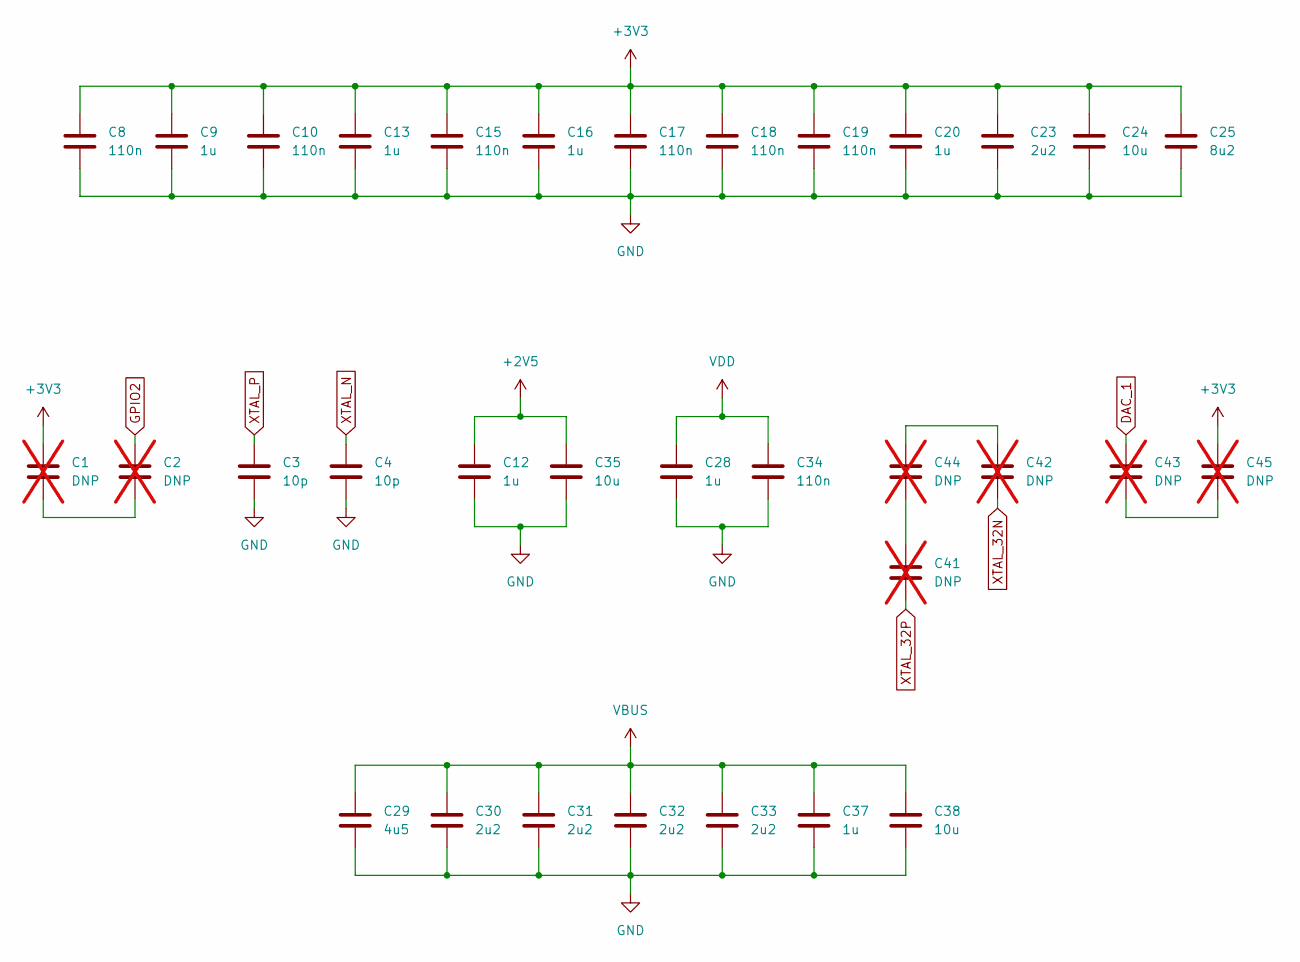
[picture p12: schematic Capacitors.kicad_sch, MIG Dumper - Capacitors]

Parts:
C1: DNP; C_1206_3216Metric_Pad1.33x1.80mm_HandSolder; not fitted
C2, C41, C42, C43: DNP; C_0603_1608Metric; not fitted
C3, C4: 10p; C_0603_1608Metric
C8, C10, C15, C17, C18, C19, C34: 110n; C_0603_1608Metric
C9, C12, C13, C16, C20, C28, C37: 1u; C_0603_1608Metric
C23, C30, C31, C32, C33: 2u2; C_0603_1608Metric
C24, C35, C38: 10u; C_1206_3216Metric_Pad1.33x1.80mm_HandSolder
C25: 8u2; C_1206_3216Metric_Pad1.33x1.80mm_HandSolder
C29: 4u5; C_1206_3216Metric_Pad1.33x1.80mm_HandSolder
C44, C45: DNP; C_0201_0603Metric; not fitted

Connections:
+2V5: C12.1, C35.1; also elsewhere on the board
+3V3: C1.1, C8.1, C9.1, C10.1, C13.1, C15.1, C16.1, C17.1, C18.1, C19.1, C20.1, C23.1, C24.1, C25.1, C45.1; also elsewhere on the board
DAC_1: C43.2; also elsewhere on the board
GND: C3.2, C4.2, C8.2, C9.2, C10.2, C12.2, C13.2, C15.2, C16.2, C17.2, C18.2, C19.2, C20.2, C23.2, C24.2, C25.2, C28.2, C29.2, C30.2, C31.2, C32.2, C33.2, C34.2, C35.2, C37.2, C38.2; also elsewhere on the board
GPIO2: C2.1; also elsewhere on the board
unnamed: C1.2, C2.2
unnamed: C41.1, C44.1
unnamed: C42.1, C44.2
unnamed: C43.1, C45.2
VBUS: C29.1, C30.1, C31.1, C32.1, C33.1, C37.1, C38.1; also elsewhere on the board
VDD: C28.1, C34.1; also elsewhere on the board
XTAL_32N: C42.2; also elsewhere on the board
XTAL_32P: C41.2; also elsewhere on the board
XTAL_N: C4.1; also elsewhere on the board
XTAL_P: C3.1; also elsewhere on the board

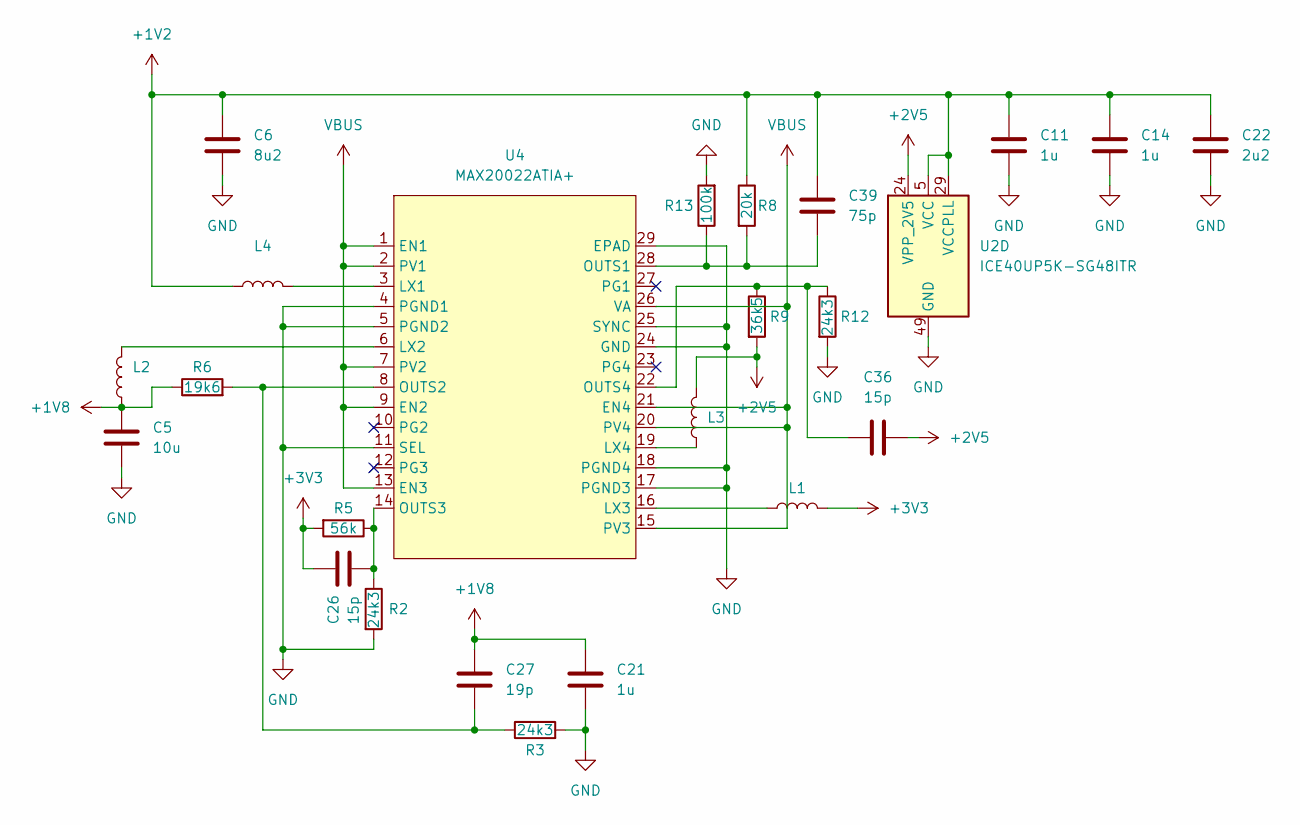
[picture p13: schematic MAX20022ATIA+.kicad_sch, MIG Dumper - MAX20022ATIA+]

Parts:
C5: 10u; C_1206_3216Metric_Pad1.33x1.80mm_HandSolder
C6: 8u2; C_1206_3216Metric_Pad1.33x1.80mm_HandSolder
C11, C14, C21: 1u; C_0603_1608Metric
C22: 2u2; C_0603_1608Metric
C26, C36: 15p; C_0603_1608Metric
C27: 19p; C_0603_1608Metric
C39: 75p; C_0603_1608Metric
L1, L2, L3, L4: LQM21PN1R5MEHD; L_0805_2012Metric_Pad1.15x1.40mm_HandSolder
R2, R3, R12: 24k3; R_0603_1608Metric
R5: 56k; R_0603_1608Metric
R6: 19k6; R_0603_1608Metric
R8: 20k; R_0603_1608Metric
R9: 36k5; R_0603_1608Metric
R13: 100k; R_0603_1608Metric
U2: ICE40UP5K-SG48ITR; QFN-48-1EP_7x7mm_P0.5mm_EP5.15x5.15mm
U4: MAX20022ATIA+; TQFN-28-1EP_5x5mm_P0.5mm_EP2.7x2.7mm

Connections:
+1V2: C6.1, C11.1, C14.1, C22.1, C39.1, L4.1, R8.1, U2.5 (VCC), U2.29 (VCCPLL), U2.30 (VCC)
+1V8: C5.1, C21.1, C27.1, L2.1, R6.1; also elsewhere on the board
+2V5: C36.1, L3.2, R9.2, U2.24 (VPP_2V5); also elsewhere on the board
+3V3: C26.1, L1.2, R5.2; also elsewhere on the board
GND: C5.2, C6.2, C11.2, C14.2, C21.2, C22.2, R2.2, R3.2, R12.2, R13.2, U2.49 (GND), U4.4 (PGND1), U4.5 (PGND2), U4.11 (SEL), U4.17 (PGND3), U4.18 (PGND4), U4.24 (GND), U4.25 (SYNC), U4.29 (EPAD); also elsewhere on the board
unnamed: L4.2, U4.3 (LX1)
unnamed: L2.2, U4.6 (LX2)
unnamed: L1.1, U4.16 (LX3)
unnamed: L3.1, U4.19 (LX4)
unnamed: C39.2, R8.2, R13.1, U4.28 (OUTS1)
unnamed: C27.2, R3.1, R6.2, U4.8 (OUTS2)
unnamed: C26.2, R2.1, R5.1, U4.14 (OUTS3)
unnamed: C36.2, R9.1, R12.1, U4.22 (OUTS4)
VBUS: U4.1 (EN1), U4.2 (PV1), U4.7 (PV2), U4.9 (EN2), U4.13 (EN3), U4.15 (PV3), U4.20 (PV4), U4.21 (EN4), U4.26 (VA); also elsewhere on the board

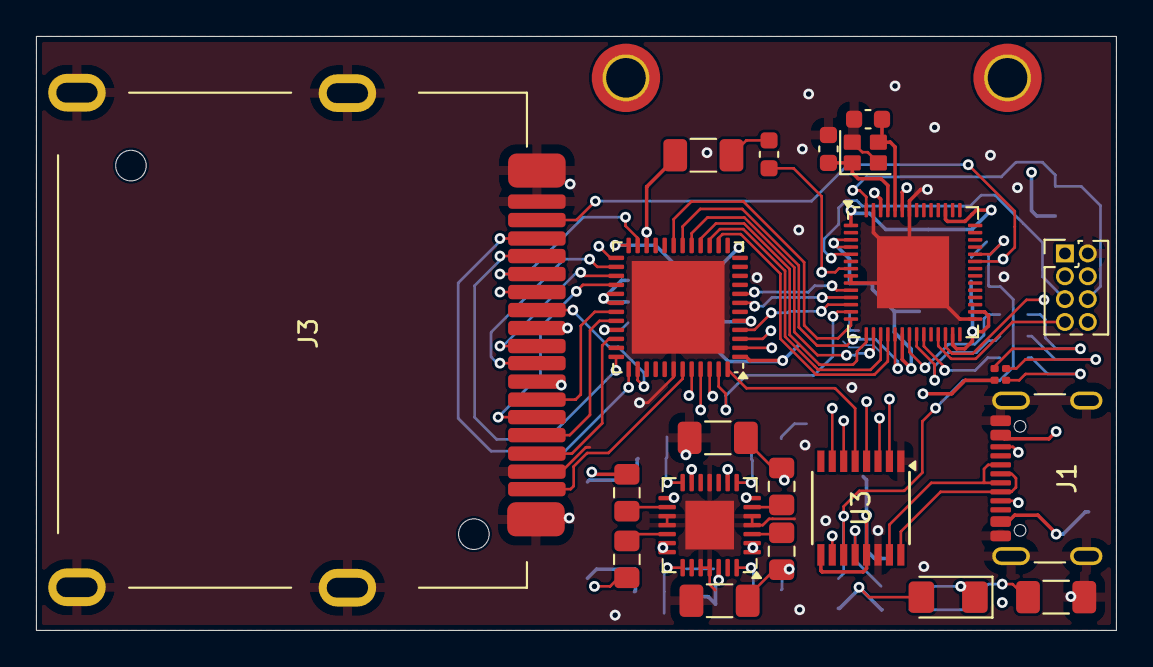
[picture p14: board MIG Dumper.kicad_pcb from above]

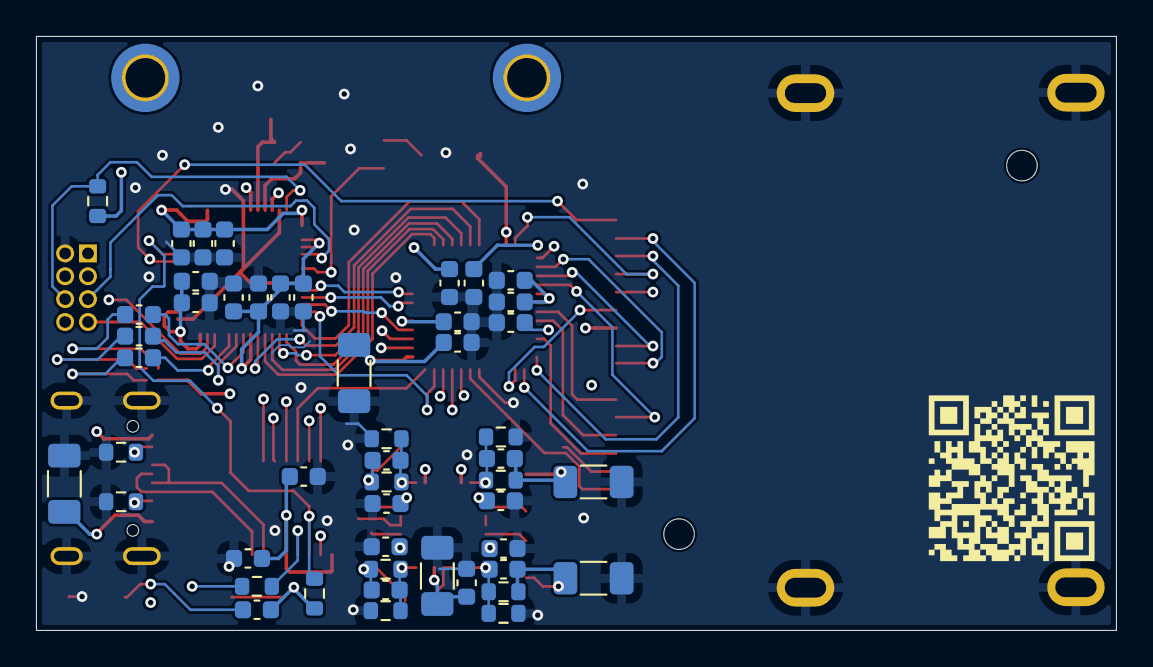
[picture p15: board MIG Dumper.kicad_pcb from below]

Board: 4 copper layers, 60.0 x 33.0 mm, 73 parts (49 on the bottom side), 66 nets.

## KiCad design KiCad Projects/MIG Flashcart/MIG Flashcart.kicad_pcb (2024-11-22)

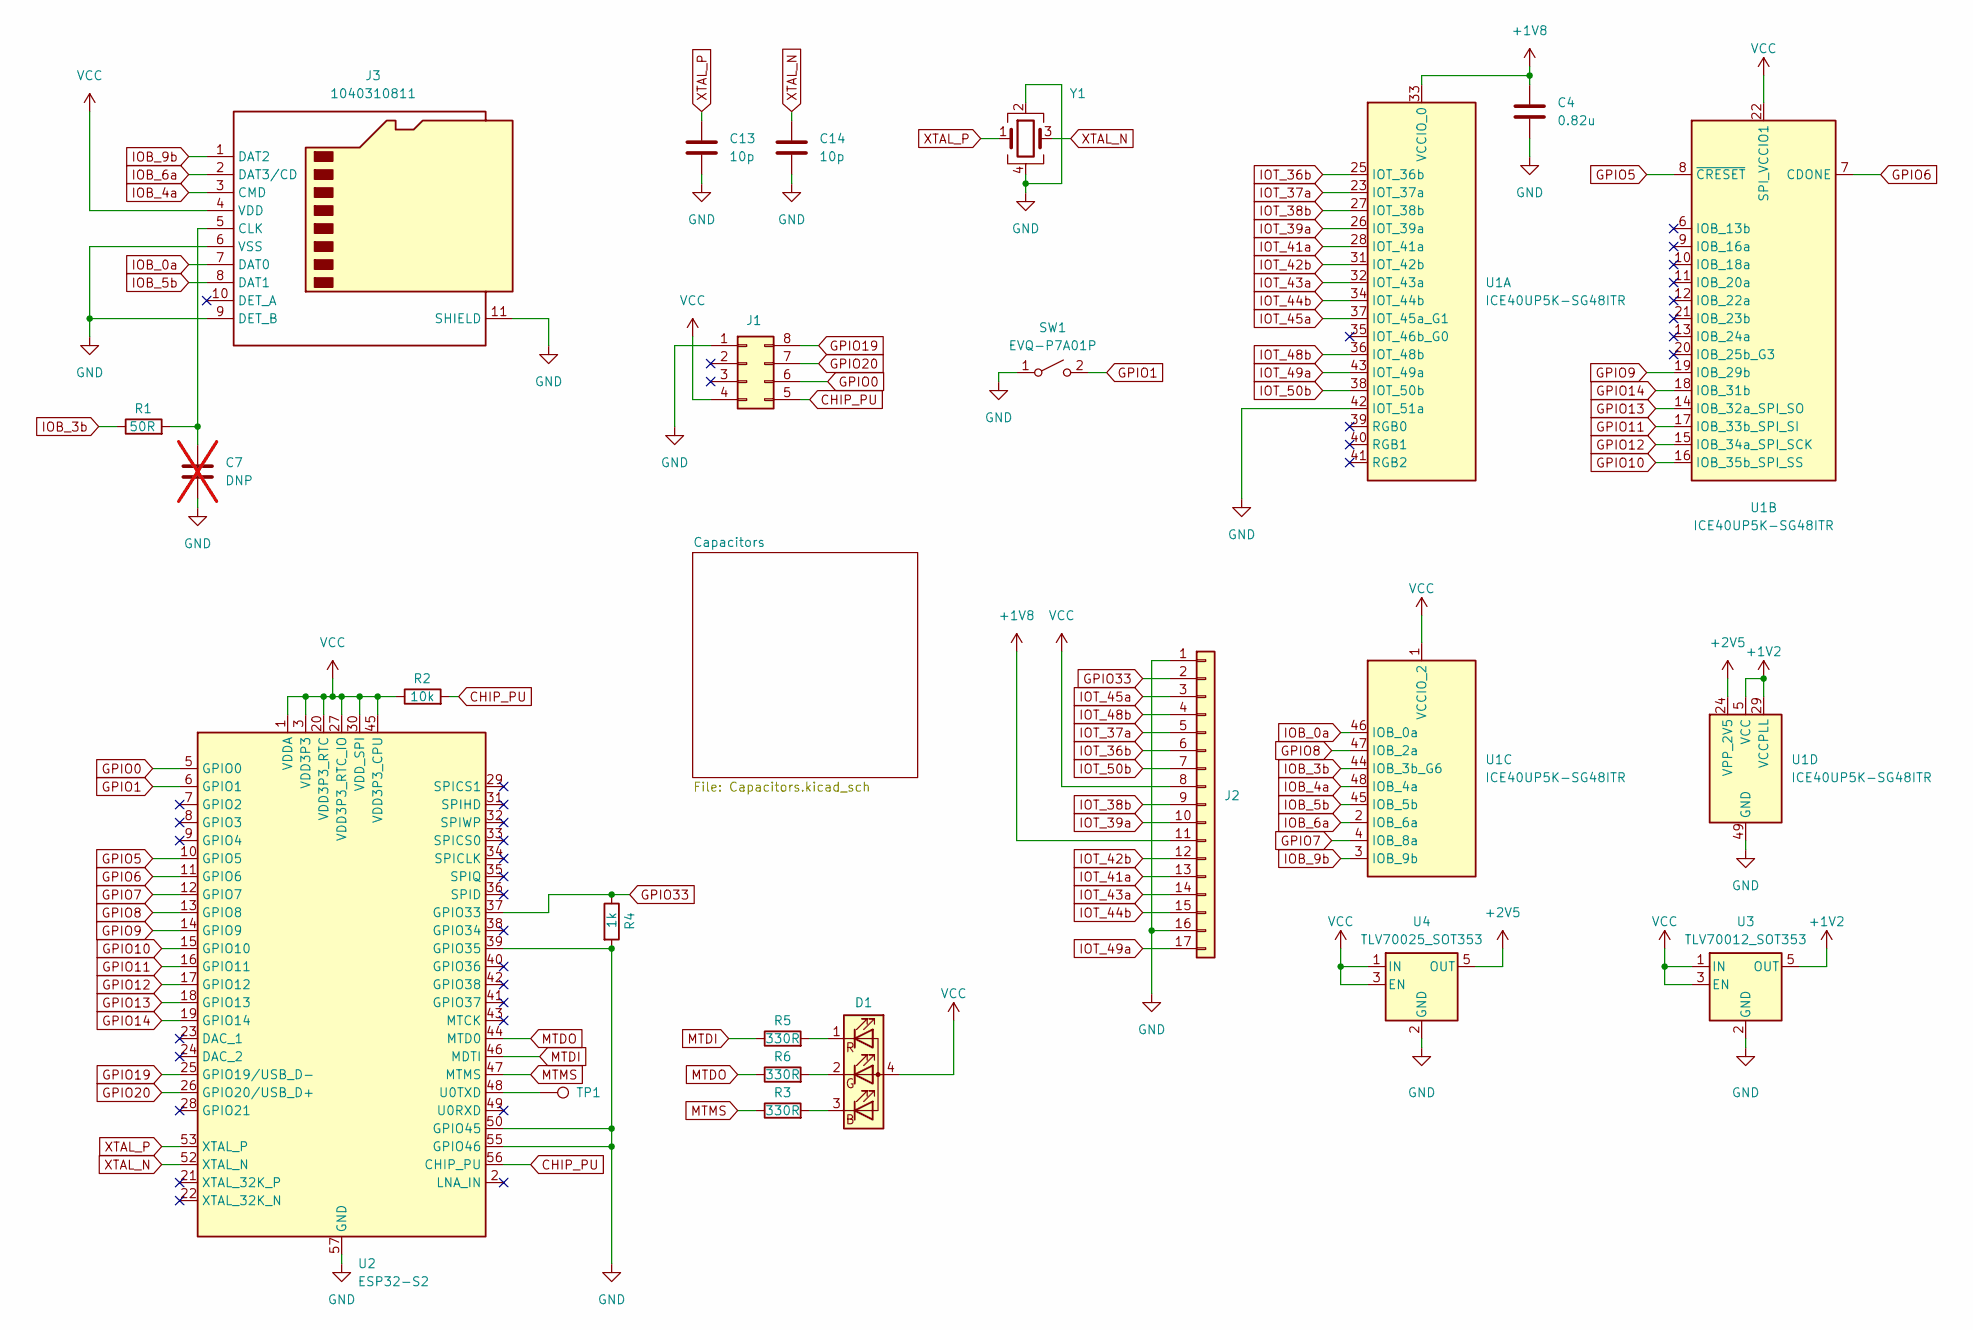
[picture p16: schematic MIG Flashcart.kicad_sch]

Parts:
C4: 0.82u; C_0201_0603Metric
C7: DNP; C_0201_0603Metric; not fitted
C13, C14: 10p; C_0201_0603Metric
D1: UHD111A-FKA-C3K23E1L3VG5ZB3Z3; SMD4_UHD111A-FKA_CRW
J1: Conn_02x04_Counter_Clockwise; PinSocket_2x04_P1.27mm_Vertical_SMD
J2: Conn_01x17; Cartridge_Pins
J3: 1040310811; microSD_HC_Molex_104031-0811
R1: 50R; R_0201_0603Metric
R2: 10k; R_0201_0603Metric
R3, R5, R6: 330R; R_0201_0603Metric
R4: 1k; R_0201_0603Metric
SW1: EVQ-P7A01P; SW_SPST_EVQP7A
TP1: TestPoint; TestPoint_Pad_D0.5mm
U1: ICE40UP5K-SG48ITR; QFN-48-1EP_7x7mm_P0.5mm_EP5.15x5.15mm
U2: ESP32-S2; QFN-56-1EP_7x7mm_P0.4mm_EP4x4mm
U3: TLV70012_SOT353; SOT-353_SC-70-5
U4: TLV70025_SOT353; SOT-353_SC-70-5
Y1: ECS-400-10-37B2-CKY-TR; Crystal_SMD_SeikoEpson_FA128-4Pin_2.0x1.6mm

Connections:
+1V2: U1.5 (VCC), U1.29 (VCCPLL), U1.30 (VCC), U3.5 (OUT); also elsewhere on the board
+1V8: C4.1, J2.11, U1.33 (VCCIO_0)
+2V5: U1.24 (VPP_2V5), U4.5 (OUT); also elsewhere on the board
CHIP_PU: J1.5, R2.2, U2.56 (CHIP_PU)
GND: C4.2, C7.2, C13.2, C14.2, J1.1, J2.1, J2.16, J3.6 (VSS), J3.9 (DET_B), J3.11 (SHIELD), R4.2, SW1.1 (A), U1.42 (IOT_51a), U1.49 (GND), U2.39 (GPIO35), U2.50 (GPIO45), U2.55 (GPIO46), U2.57 (GND), U3.2 (GND), U4.2 (GND), Y1.2, Y1.4; also elsewhere on the board
GPIO0: J1.6, U2.5 (GPIO0)
GPIO1: SW1.2 (B), U2.6 (GPIO1)
GPIO5: U1.8 (~CRESET), U2.10 (GPIO5)
GPIO6: U1.7 (CDONE), U2.11 (GPIO6)
GPIO7: U1.4 (IOB_8a), U2.12 (GPIO7)
GPIO8: U1.47 (IOB_2a), U2.13 (GPIO8)
GPIO9: U1.19 (IOB_29b), U2.14 (GPIO9)
GPIO10: U1.16 (IOB_35b_SPI_SS), U2.15 (GPIO10)
GPIO11: U1.17 (IOB_33b_SPI_SI), U2.16 (GPIO11)
GPIO12: U1.15 (IOB_34a_SPI_SCK), U2.17 (GPIO12)
GPIO13: U1.14 (IOB_32a_SPI_SO), U2.18 (GPIO13)
GPIO14: U1.18 (IOB_31b), U2.19 (GPIO14)
GPIO19: J1.8, U2.25 (GPIO19/USB_D-)
GPIO20: J1.7, U2.26 (GPIO20/USB_D+)
GPIO33: J2.2, R4.1, U2.37 (GPIO33)
IOB_0a: J3.7 (DAT0), U1.46 (IOB_0a)
IOB_3b: R1.1, U1.44 (IOB_3b_G6)
IOB_4a: J3.3 (CMD), U1.48 (IOB_4a)
IOB_5b: J3.8 (DAT1), U1.45 (IOB_5b)
IOB_6a: J3.2 (DAT3/CD), U1.2 (IOB_6a)
IOB_9b: J3.1 (DAT2), U1.3 (IOB_9b)
IOT_36b: J2.6, U1.25 (IOT_36b)
IOT_37a: J2.5, U1.23 (IOT_37a)
IOT_38b: J2.9, U1.27 (IOT_38b)
IOT_39a: J2.10, U1.26 (IOT_39a)
IOT_41a: J2.13, U1.28 (IOT_41a)
IOT_42b: J2.12, U1.31 (IOT_42b)
IOT_43a: J2.14, U1.32 (IOT_43a)
IOT_44b: J2.15, U1.34 (IOT_44b)
IOT_45a: J2.3, U1.37 (IOT_45a_G1)
IOT_48b: J2.4, U1.36 (IOT_48b)
IOT_49a: J2.17, U1.43 (IOT_49a)
IOT_50b: J2.7, U1.38 (IOT_50b)
MTDI: R5.1, U2.46 (MDTI)
MTDO: R6.1, U2.44 (MTD0)
MTMS: R3.1, U2.47 (MTMS)
unnamed: D1.3 (BK), R3.2
unnamed: D1.2 (GK), R6.2
unnamed: D1.1 (RK), R5.2
unnamed: C7.1, J3.5 (CLK), R1.2
unnamed: TP1.1, U2.48 (U0TXD)
VCC: D1.4 (A), J1.4, J2.8, J3.4 (VDD), R2.1, U1.1 (VCCIO_2), U1.22 (SPI_VCCIO1), U2.1 (VDDA), U2.3 (VDD3P3), U2.4 (VDD3P3), U2.20 (VDD3P3_RTC), U2.27 (VDD3P3_RTC_IO), U2.30 (VDD_SPI), U2.45 (VDD3P3_CPU), U2.51 (VDDA), U2.54 (VDDA), U3.1 (IN), U3.3 (EN), U4.1 (IN), U4.3 (EN); also elsewhere on the board
XTAL_N: C14.1, U2.52 (XTAL_N), Y1.3
XTAL_P: C13.1, U2.53 (XTAL_P), Y1.1

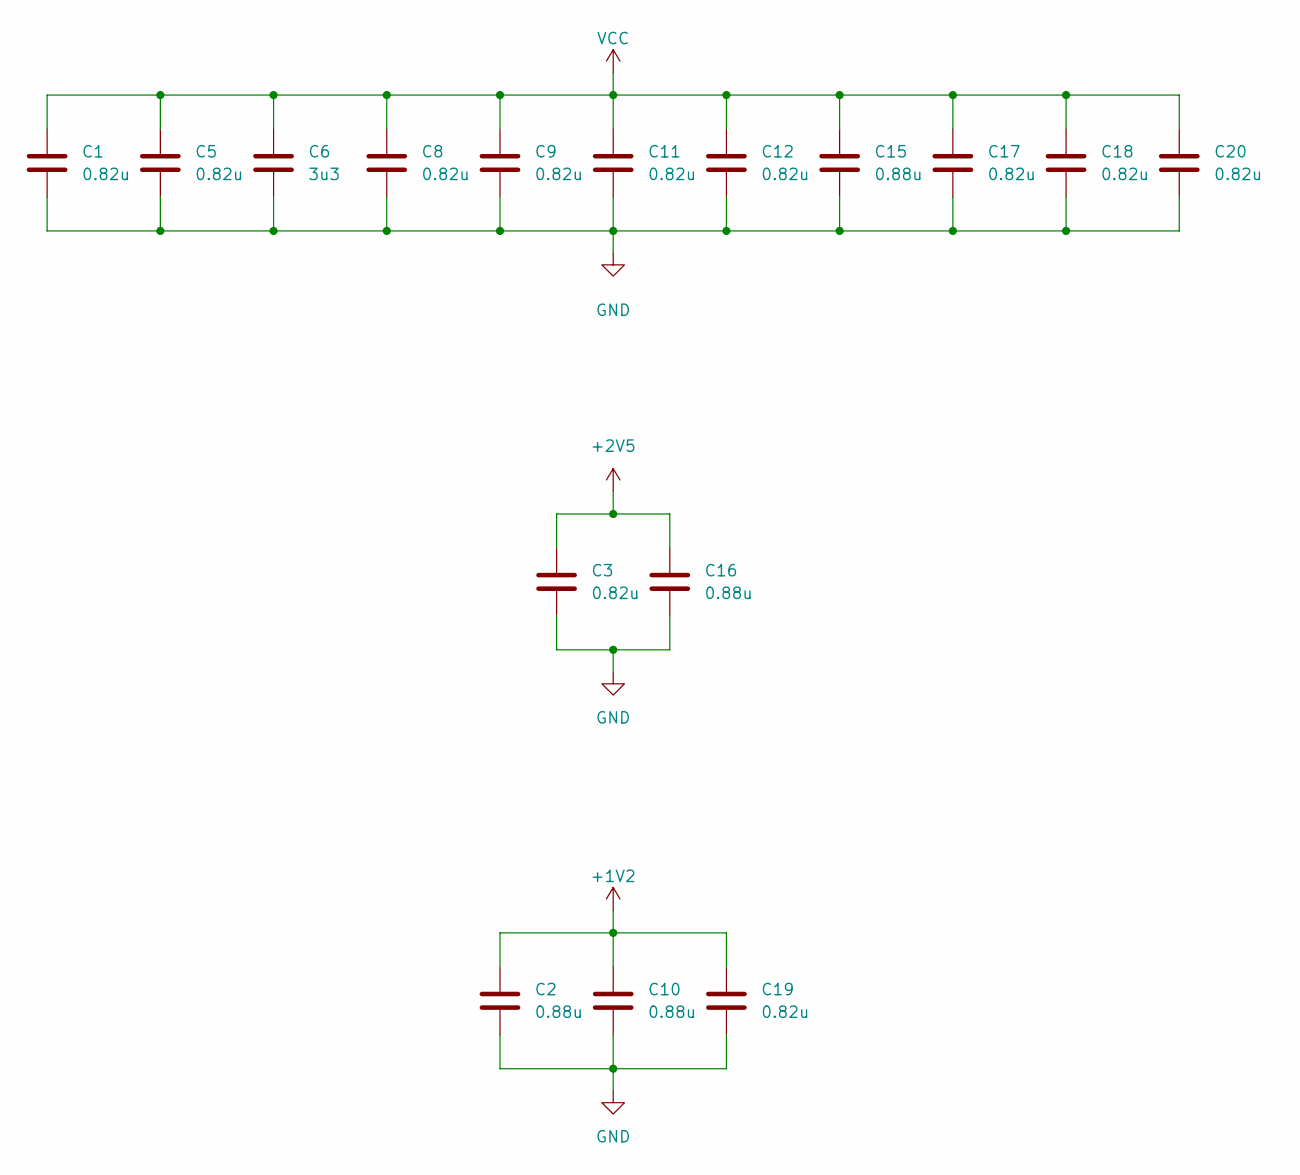
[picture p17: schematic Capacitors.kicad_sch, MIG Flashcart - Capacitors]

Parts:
C1, C3, C5, C8, C9, C11, C12, C17, C18, C19, C20: 0.82u; C_0201_0603Metric
C2, C10, C15, C16: 0.88u; C_0201_0603Metric
C6: 3u3; C_0402_1005Metric

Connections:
+1V2: C2.1, C10.1, C19.1; also elsewhere on the board
+2V5: C3.1, C16.1; also elsewhere on the board
GND: C1.2, C2.2, C3.2, C5.2, C6.2, C8.2, C9.2, C10.2, C11.2, C12.2, C15.2, C16.2, C17.2, C18.2, C19.2, C20.2; also elsewhere on the board
VCC: C1.1, C5.1, C6.1, C8.1, C9.1, C11.1, C12.1, C15.1, C17.1, C18.1, C20.1; also elsewhere on the board

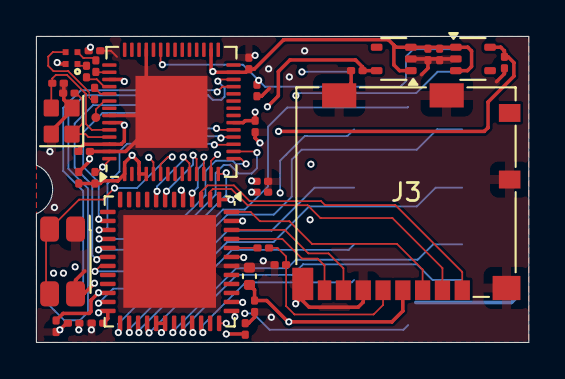
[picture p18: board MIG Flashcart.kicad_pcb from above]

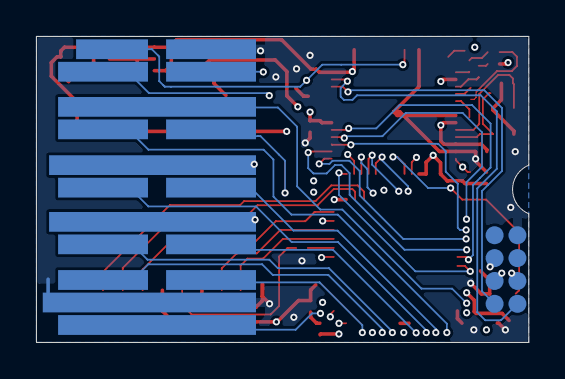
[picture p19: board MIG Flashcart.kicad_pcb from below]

Board: 4 copper layers, 27.4 x 17.0 mm, 37 parts (2 on the bottom side), 49 nets.

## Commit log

2024-10-18 Initial commit
    First commit including KiCad project files and boardview files for both the MIG Flashcart and Dumper.
    [104031-0811.step, Capacitors.kicad_sch, ECS-400-10-37B2-CKY-TR.step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]
2024-11-22 Updated Flashcart PCB, uploaded Flashcart BOM
    Revised the Flashcart PCB to the newer revision of the MIG v2, as well as added DigiKey and Mouser BOMs for the Flashcart. One capacitor measurement on the Dumper PCB was corrected as well.
    [Capacitors.kicad_sch, MIG Dumper - DigiKey.csv, MIG Dumper - Mouser.xls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]
2025-07-16 Updated READMEs
    Updated READMEs to indicate that the flashcart PCB has been confirmed to work. Also updated the boardview README since the obdata script has been upstreamed.
